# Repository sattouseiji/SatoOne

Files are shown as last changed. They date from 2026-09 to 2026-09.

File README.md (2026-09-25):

# SatoOne

**Um computador pessoal portátil em desenvolvimento.**

SatoOne combina Linux, tela touch e teclado físico em um equipamento compacto, concebido para produtividade móvel, automações e acesso a um ambiente computacional completo.

[**Conheça o SatoOne**](https://sattouseiji.github.io/SatoOne/) · [**Atualização e health check — 25/09**](https://sattouseiji.github.io/SatoOne/reports/satoone-health-2026-09-25.html) · [**Acompanhe o desenvolvimento**](https://github.com/sattouseiji/SatoOne/discussions)

## Estado atual

A versão V0 é um protótipo físico funcional. Já foram integrados e validados:

- Radxa Zero 3W com Debian;
- display touch de 5 polegadas;
- teclado físico integrado;
- conectividade Wi-Fi e periféricos USB;
- funcionamento portátil por bateria;
- gabinete próprio produzido por impressão 3D.

A [página oficial](https://sattouseiji.github.io/SatoOne/) apresenta fotos e uma demonstração em vídeo do protótipo real em funcionamento.

O baseline elétrico atual usa **LiPo Rontek 1S 10 Ah + UPS antigo sem suporte 18650**, preservando switch e distribuição. O responsável confirmou funcionamento estável do conjunto completo, com aproximadamente **4,92 V** na saída do UPS. O IP5310 foi testado e permanece experimental, fora da montagem atual.

O health check de 25/09 encontrou recursos e conectividade disponíveis, mas falha na inicialização do aplicativo e atenção térmica (**73,3–75,6 °C**). As prioridades são corrigir a inicialização, medir o UPS modificado para um Back mais fino e implementar telemetria com INA219. Autonomia mínima de duas horas continua como meta, sem ensaio conclusivo.

A direção inicial de 15–16/09 foi revisada em 25/09/2026 após testes físicos. Consulte o [plano de desenvolvimento V1](docs/development/V1_DEVELOPMENT_PLAN.md), o [sistema de energia](docs/electronics/V1_POWER_SYSTEM.md), o [plano da nova case](docs/cad/V1_ENCLOSURE_PLAN.md) e os [critérios de aceitação](docs/development/V1_ACCEPTANCE_PLAN.md).

## Visão do produto

O objetivo é oferecer um computador realmente pessoal: compacto, configurável e capaz de executar ferramentas Linux sem depender do formato tradicional de notebook.

O projeto está em fase de desenvolvimento e validação. O produto ainda não está disponível para venda, e especificações, formato, preço e cronograma podem mudar.

## Acompanhe e manifeste interesse

As principais etapas serão comunicadas publicamente. Para registrar interesse na versão final, futuras oportunidades de acesso antecipado, health checks, notícias e vídeos, escreva para [sattoumarcelo@gmail.com](mailto:sattoumarcelo@gmail.com) ou participe das [discussões oficiais](https://github.com/sattouseiji/SatoOne/discussions). O programa de atualizações ainda está em preparação.

Preço e formas de pagamento serão anunciados em breve. Manifestar interesse não constitui reserva, compra, investimento, garantia de acesso antecipado ou garantia de lançamento.

## Propriedade intelectual

SatoOne é um projeto de produto proprietário. O conteúdo desta versão é disponibilizado somente para acompanhamento e avaliação. Consulte o arquivo [LICENSE](LICENSE) para os termos aplicáveis.

Versões anteriores que tenham sido expressamente publicadas sob outra licença permanecem sujeitas aos termos válidos no momento de sua publicação.

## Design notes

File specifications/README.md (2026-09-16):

# Specifications

Esta pasta é a fonte de verdade por disciplina. Cada mudança deve declarar estado (`[PHYSICALLY VALIDATED]`, `[CURRENT DESIGN]`, `[PURCHASED]`, `[IN TRANSIT]`, `[PENDING VALIDATION]` ou `[FUTURE/IDEA]`), evidência e data de atualização. Informação substituída permanece marcada como `SUPERSEDED`.

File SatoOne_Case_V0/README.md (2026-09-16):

# SatoOne Case V0 — definitiva

Status: **PHYSICALLY VALIDATED / V0 DEFINITIVA**

Estes são os arquivos de impressão preservados da case usada na V0 funcional do SatoOne.

## Arquivos

- `SatoOne_Case_V0_Front.stl`: frente, originada de `SatoOne_V3_1_FRONT_ORIGINAL_HOLES_M2x5.stl`;
- `SatoOne_Case_V0_Back.stl`: traseira com abertura do UPS, originada de `SatoOne_V3_5_BACK_UPS_Opening_20_40x11_76 (1).stl`;
- `SatoOne_Case_V0_Clamps.stl`: conjunto de presilhas, originado de `SatoOne_V2_6_CLAMPS_ALL.stl`.

Os nomes antigos permanecem registrados aqui para rastreabilidade; o conteúdo geométrico não foi alterado durante a organização para Git.

## Validação

A montagem V0 foi concluída e funciona com Radxa Zero 3W, display Waveshare 5DP-CAPLCD-H, touchscreen USB, BBQ20KBD, hub USB e UPS.

Na revisão funcional mais recente, Radxa e hub trocaram de posição, o hub ficou próximo à parede, a ventilação acompanhou a Radxa e a profundidade nominal do Back foi reduzida de 40 para 34 mm. O pitch de projeto da Radxa é 58 × 23 mm com postes de 10 mm; o pitch atual validado do hub é 52 × 15,25 mm. Essas notas não alteram os STLs preservados.

## Impressão

As configurações exatas de material, orientação, suporte e perfil do slicer usadas na validação física ainda precisam ser registradas. Não inventar parâmetros ausentes.

## Fonte editável

Esta entrega contém as malhas STL definitivas. O arquivo CAD paramétrico/editável correspondente não estava presente nesta pasta na preparação inicial do repositório. Adicioná-lo futuramente sem substituir silenciosamente estes STLs.

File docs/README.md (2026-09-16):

# Documentação de engenharia

Use esta pasta para documentação que explica como construir, operar, integrar e entregar o SatoOne. As regras e requisitos normativos permanecem em `specifications/`.

## Rotas principais

- `product/`: posicionamento comercial e política de comunicação pública.
- `development/V1_DEVELOPMENT_PLAN.md`: plano integrado da V1.
- `development/V1_ACCEPTANCE_PLAN.md`: critérios e gates de validação.
- `electronics/V1_POWER_SYSTEM.md`: energia, proteção e telemetria.
- `cad/V1_ENCLOSURE_PLAN.md`: direção de case e cooling.

As decisões técnicas atuais da V1 foram tomadas em 2026-09-15 e consolidadas na documentação em 2026-09-16.

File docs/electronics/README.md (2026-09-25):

# Eletrônica

A montagem atual usa **LiPo 10 Ah → UPS antigo sem suporte 18650 → switch → distribuição existente**, validada conforme relato físico com ~4,92 V sob carga completa. IP5310 permanece experimental; INA219, autonomia e monitoramento são próximos passos.

Ver [sistema de energia](V1_POWER_SYSTEM.md) e [registro físico de 25/09](../../knowledge/hardware/2026-09-25-power-baseline.md).

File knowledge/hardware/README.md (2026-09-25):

# Hardware

## Baseline atual — 2026-09-25

LiPo 10 Ah recebida e integrada ao UPS antigo sem suporte 18650; saída ~4,92 V estável com o sistema completo, conforme relato do responsável. IP5310 testado e não adotado. Ver [medidas, validação e pendências](2026-09-25-power-baseline.md). Os estados de compra abaixo são o histórico de 15–16/09; INA219 segue sem confirmação de recebimento ou integração.

## Baseline V0

Radxa Zero 3W, display Waveshare 5DP-CAPLCD-H, teclado BlackBerry Q10/BBQ20KBD, hub USB, UPS e duas 18650 estão fisicamente disponíveis. A V0 funciona e foi registrada em fotos e vídeo.

## Marco de 2026-09-15

- health check integral executado;
- 1h04 registrado inicialmente, mas posteriormente marcado como não definitivo; ensaio final V0 pendente;
- SoC observado em 70,6 °C e pico de 77,5 °C;
- caminho HDMI via flat, touch/teclado via hub e distribuição 5 V pós-switch fisicamente validados;
- Li-Po 1S de 10.000 mAh, IP5310 e INA219 comprados em 2026-09-16 e em trânsito;
- case menor, bateria atrás do teclado e cooling condicionado a testes definidos como direção mecânica.

Os itens H018, H019 e H025 estão comprados/em trânsito, mas não fisicamente validados. Consultar o BOM para itens superseded, opcionais e pendentes.

Registrar compatibilidade, medições, testes de integração e substituições. Atualizar o BOM sempre que o status de compra ou peça mudar.

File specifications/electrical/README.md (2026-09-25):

# Electrical

## Baseline atual — 2026-09-25

**[CURRENT WORKING DESIGN] [PHYSICALLY VALIDATED — relato do responsável]**

`LiPo 1S 10 Ah → UPS antigo sem suporte 18650 → switch → distribuição existente`.

Saída relatada ~4,92 V sob carga completa, sem desligamentos ou brownout observado. Preservar a PCB e seus componentes. IP5310 fora da montagem atual, apenas experimental. [Registro físico e limites](../../knowledge/hardware/2026-09-25-power-baseline.md). As seções abaixo preservam o histórico.

## V0 [PHYSICALLY VALIDATED]

```text
2×18650 → LX-2BUPS/equivalente → switch no +5 V → barramento
                                                  ├─ Radxa
                                                  ├─ Hub
                                                  └─ Display
```

- cargas principais usam ramos próprios; Radxa/hub não distribuem a potência total;
- GND é comum e não passa pelo switch;
- a fiação pós-switch está pronta e funcional;
- adaptadores USB-C macho → borne são passivos;
- aproximadamente 4,8 V foram observados com o sistema e YouTube em operação;
- em bateria baixa, células chegaram a ~2,9 V sob carga/~3,14 V em repouso e a saída colapsou para ~2,0 V após desligamento;
- com switch OFF, as cargas desligam, mas o UPS e seu LED permanecem energizados.

O registro anterior de 1h04 fica **SUPERSEDED como autonomia definitiva**. O ensaio com carga completa iniciado em 2026-09-15 às ~18:40 ainda não possui duração final validada.

## Plano V1 de 16/09 [SUPERSEDED em 25/09]

`Li-Po 1S 10 Ah → IP5310 → 5 V → switch existente → distribuição existente`.

Li-Po, IP5310 e INA219 estão [PURCHASED] [IN TRANSIT], com entrega prevista até 2026-09-19. Validar antes da integração:

- medidas, etiqueta, A58/polaridade, tensão, PCM/BMS e capacidade/corrente da bateria;
- pinout, 5 V sem carga/sob carga, corrente, temperatura, proteções e operação simultânea do IP5310;
- limite, queda, dissipação e posição do INA219 antes ou depois do boost;
- coexistência entre Power dedicado da tela e VBUS do USB Touch.

Fusível/PPTC é [OPTIONAL / FUTURE]. A arquitetura anterior com charger/boost separados, fusível 7,5 A obrigatório, XT30, AWG18, MAX17048 e INA226 fica **SUPERSEDED** para a primeira integração.

Nunca ligar Li-Po 1S diretamente a cargas de 5 V, assumir pinout ou usar a saída regulada de 5 V como porcentagem de bateria. Consultar `docs/electronics/V1_POWER_SYSTEM.md` e `skills/satoone-development/references/27_power.md`.

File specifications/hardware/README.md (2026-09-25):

# Hardware

Especifica plataforma, componentes físicos, interfaces e compatibilidade. Consulte `BOM.md` antes de comprar, instalar ou substituir peças.

## Observação operacional — 2026-09-17

[PHYSICALLY VALIDATED — leitura no dispositivo] O sistema auditado usa microSD de 59,5 GiB (classe nominal de 64 GB) para a partição raiz; a eMMC de 29,1 GiB (classe nominal de 32 GB) está presente e não hospeda a raiz atual. Essa observação não altera a capacidade interna especificada da Radxa. Ver `knowledge/benchmarks/2026-09-17-health-check.md` e H031 no BOM. Fabricante, marcação física e compra do cartão não foram verificados.

## Atualização operacional — 2026-09-25

A raiz está na eMMC de 29,1 GiB; nenhum microSD foi enumerado nesta coleta. A observação de 17/09 acima descreve o boot daquela data. Alimentação atual: LiPo 10 Ah + UPS antigo sem suporte 18650; ver [baseline físico](../../knowledge/hardware/2026-09-25-power-baseline.md).

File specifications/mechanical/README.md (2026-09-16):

# Mechanical

## V0 definitiva

A V0 física está funcional e seus três STLs permanecem preservados em `SatoOne_Case_V0/`. O envelope externo anteriormente registrado é aproximadamente 130 × 155 × 44 mm. A profundidade nominal do Back foi reduzida de 40 para 34 mm na iteração funcional; esses valores descrevem referências diferentes e não devem ser combinados sem nova medição. O CAD paramétrico correspondente não está presente; não tratar STL como fonte editável.

Layout mais recente: Radxa e hub trocaram de posição; hub junto à parede, Radxa na região anterior do hub e ventilação acompanhando a Radxa. Mounting pitch de projeto: Radxa 58 × 23 mm; hub fisicamente validado 52 × 15,25 mm. Postes da Radxa: 10 mm de altura.

## V1 comercial — decisão de 2026-09-15

- colocar a bateria pouch atrás do teclado;
- remover o volume do UPS e das duas 18650;
- reduzir significativamente o Back usando a pouch anunciada com ~11,1 mm e o IP5310 compacto, sem fixar dimensão final antes do recebimento;
- manter bateria, eletrônica, display e teclado removíveis;
- não comprimir nem colar permanentemente a Li‑Po;
- preservar acesso a portas e alívio de cabos;
- melhorar caminho térmico e ventilação passiva;
- reservar fan de 30 mm, instalando-o somente se ensaios exigirem.

Criar nova fonte paramétrica para a V1 sem sobrescrever a V0. Produzir coupons para bateria, conectores, standoffs, insertos, ventilação e cabos antes da impressão completa. Consultar `docs/cad/V1_ENCLOSURE_PLAN.md`.

## Fabricação

Projetar dentro do volume da Bambu Lab A1 Mini. PLA serve para protótipos; escolher material de produção somente após térmica, impacto, acabamento e processo de montagem serem validados.

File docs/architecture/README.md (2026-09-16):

# Arquitetura

Árvore de software: GUI → Widgets → Services → Drivers → Database → AI → Network → Storage. Dependências fluem para baixo; widgets não concentram regra de negócio.

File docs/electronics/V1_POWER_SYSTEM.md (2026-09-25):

# Sistema de energia e telemetria — V1

## Revisão vigente — 2026-09-25

**LiPo 10 Ah → UPS antigo sem suporte 18650 → switch → distribuição existente.** Validada fisicamente conforme relato do responsável: ~4,92 V estáveis com o conjunto completo, sem desligamentos ou brownout observado. Preservar PCB, boost, carga e conectores; não cortar a placa.

LiPo recebida: 111,2 × 64,99 × 10,99 mm medidos; CAD 111,2 × 65,0 × 11,0 mm. Proteção integrada observada. IP5310 testado e não adotado; apenas experimental. INA219, autonomia, alertas e shutdown permanecem pendentes. Ver [evidências e próximos passos](../../knowledge/hardware/2026-09-25-power-baseline.md).

## Histórico de 16/09 — plano IP5310 [SUPERSEDED]

O plano e a sequência de testes abaixo são preservados como histórico; não orientam a montagem atual.

**Direção técnica:** 2026-09-15
**Compra registrada:** 2026-09-16
**Estado:** componentes principais [PURCHASED] [IN TRANSIT], entrega prevista até 2026-09-19

## Arquitetura proposta em 16/09 [SUPERSEDED]

```text
Li-Po Rontek/A58 1S 10 Ah
  → módulo IP5310
  → saída 5 V
  → switch mecânico existente no positivo
  → distribuição pós-switch existente
      ├─ Radxa
      ├─ Hub
      └─ Display
```

A fiação após o switch está pronta e fisicamente validada. A próxima alteração deve ocorrer somente antes do switch. GND permanece comum. Radxa e hub não devem ser usados como distribuidores principais de potência.

## Hardware comprado [PENDING VALIDATION]

| Item | Dados de anúncio/compra | Verificar no recebimento |
| --- | --- | --- |
| Li-Po | Rontek/A58, família 1165110, 1S, ~3,7 V, 10.000 mAh/~37 Wh, 1C, 113,5 × 65 × 11,1 mm | medidas, rótulo, tensão, A58/polaridade, PCM/BMS, capacidade/corrente |
| IP5310 | 1S, boost 5 V/~3,1 A, USB-C, carga integrada/power-path, ~26 × 19 × 4,9 mm | pinout, saída sem/sob carga, temperatura, proteções e uso durante carga |
| INA219 | shunt R100, borne, VCC/GND/SDA/SCL | limite de corrente, dissipação, queda, resolução e posição elétrica |

Compra não comprova especificação, compatibilidade ou segurança. Não criar encaixes finais antes de medir as peças reais.

## Telemetria

A posição do INA219 permanece [PENDING DESIGN DECISION]:

- antes do boost: melhor visibilidade da bateria;
- depois do boost: consumo agregado do sistema em 5 V.

A saída regulada de 5 V não serve sozinha como porcentagem da bateria. O software deverá mostrar carga estimada, tensão, corrente, potência e runtime; emitir low-battery warning e executar shutdown limpo antes do colapso.

## Proteção e conexão

- PCM/BMS do pack: [VERIFY EXACT PACK PROTECTION].
- Conector: A58 fêmea com rabicho, preferencialmente 22 AWG, [TO BUY / VERIFY].
- Fusível/PPTC: [OPTIONAL / FUTURE] para a primeira montagem; reavaliar na versão final.
- Não cortar o A58 original se houver conector compatível.
- Nunca ligar a Li-Po diretamente a componentes de 5 V.

## Arquitetura superseded

A recomendação anterior de charger e boost separados, boost 5 A, fusível obrigatório de 7,5 A, XT30, AWG18, MAX17048 e INA226 está **SUPERSEDED para a primeira integração V1**. Esses itens podem voltar como alternativas se os testes do IP5310/INA219 falharem.

## Teste ordenado

1. Fotografar e medir os três módulos.
2. Inspecionar bateria e identificar pinout do IP5310.
3. Testar Li-Po → IP5310 sem carga e confirmar aproximadamente 5 V.
4. Testar Radxa; Radxa + hub; sistema completo.
5. Medir tensão/temperatura com Wi-Fi, YouTube, tela, touch e teclado.
6. Testar carga USB-C durante o uso.
7. Decidir e integrar INA219.
8. Implementar leitura Debian, alertas e shutdown.
9. Medir autonomia.
10. Somente então redesenhar o Back.

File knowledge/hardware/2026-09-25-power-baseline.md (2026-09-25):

# Baseline elétrico — registro de 2026-09-25

**[CURRENT WORKING DESIGN] [PHYSICALLY VALIDATED — relato do responsável]**
Fonte: decisão e medições físicas fornecidas pelo responsável nesta data; não são medições feitas pelo health check SSH. Protótipo, sem qualificação de produção.

## Montagem adotada

`LiPo Rontek 1S 10 Ah → UPS antigo sem suporte 18650 → switch → distribuição existente`.

O banco do UPS foi confirmado como 1S/paralelo, com ~3,6 V na bateria original. Foram removidos apenas suporte e contatos das células cilíndricas; PCB principal, boost, carga, capacitores, indutor, USB-C e saídas foram preservados. Não cortar a PCB nem remover componentes para reduzir tamanho.

## Validação relatada

- **MEDIÇÃO FÍSICA:** saída UPS+/UPS− em aproximadamente **4,92 V** com Radxa, display, touch, hub e teclado funcionando simultaneamente.
- Funcionamento estável, sem desligamentos, queda significativa ou brownout observado.
- Bateria permaneceu fria e UPS em temperatura normal, conforme observação qualitativa; não foram fornecidas temperaturas numéricas.
- LiPo Rontek / 1165110: 1S, 3,7 V e 10.000 mAh nominais; PCB de proteção integrada observada.
- **MEDIÇÃO FÍSICA da LiPo:** **111,2 × 64,99 × 10,99 mm**. Referência arredondada para CAD: **111,2 × 65,0 × 11,0 mm**.

A duração do teste, corrente, capacidade efetiva e limiares da proteção não foram fornecidos. O relato valida a operação observada; autonomia e ensaio sustentado continuam pendentes.

## Alternativa testada

IP5310: carregamento, LEDs/status, boost e cargas USB-C compatíveis funcionaram, mas a integração por fios/pads no SatoOne não teve a mesma confiabilidade do UPS antigo. **[NOT USED IN CURRENT BUILD] [EXPERIMENTAL / FUTURE]**. Não substituir automaticamente o baseline.

## Próximos passos

- [x] LiPo recebida, medida e integrada; proteção observada.
- [x] Banco 1S confirmado, suporte 18650 removido e conjunto completo validado conforme relato.
- [ ] Medir dimensões finais e altura máxima da PCB do UPS.
- [ ] Planejar LiPo e UPS no mesmo plano, Back mais fino, fixação segura/removível, acesso à USB-C de carga e organização dos cabos.
- [ ] Integrar INA219, monitoramento, alerta de bateria baixa e shutdown seguro.
- [ ] Medir autonomia e térmica em cenário documentado.

Esta revisão substitui a direção IP5310 de 16/09. A distribuição pós-switch permanece preservada.

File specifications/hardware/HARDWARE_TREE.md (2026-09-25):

# Hardware Tree

```text
SatoOne V0 [PHYSICALLY VALIDATED]
├── Compute             Radxa Zero 3W, 4 GB, 32 GB eMMC
├── Display             Waveshare 5DP-CAPLCD-H, HDMI + touch USB
├── Keyboard            BlackBerry Q10 / BBQ20KBD via hub
├── Video               micro-HDMI → adaptador/flat → HDMI flat Waveshare
├── Energy              2×18650 → LX-2BUPS/equiv. → switch positivo
├── Distribution        barramento 5 V/GND → ramos Radxa, hub e display
├── USB                 Radxa → hub → touch + teclado
└── Enclosure           case V0 impressa e funcional

SatoOne atual — 2026-09-25 [CURRENT WORKING DESIGN]
├── Battery             LiPo Rontek 1S 10 Ah [RECEIVED] [PHYSICALLY VALIDATED]
├── Energy              UPS antigo sem suporte 18650, ~4,92 V sob carga
├── Switch              switch mecânico existente no positivo
├── Distribution        fiação pós-switch existente preservada
├── Telemetry           INA219 R100 [PURCHASED] [IN TRANSIT]
├── Connector           A58 fêmea com rabicho 22 AWG [TO BUY / VERIFY]
├── Protection          PCB de proteção da LiPo observada; limiares não ensaiados
├── Cooling             passivo primeiro; fan 30 mm condicional
└── Enclosure           LiPo e UPS no mesmo plano; medir PCB/altura do UPS
```

A arquitetura anterior de charger/boost separados, fusível 7,5 A, XT30, AWG18, MAX17048 e INA226 fica **SUPERSEDED** para a primeira montagem V1. Compra não implica validação física; consultar `skills/satoone-development/references/27_power.md`.

IP5310: [NOT USED IN CURRENT BUILD] [EXPERIMENTAL / FUTURE]. INA219: integração futura; recebimento não reconfirmado. Fonte: [baseline de 25/09](../../knowledge/hardware/2026-09-25-power-baseline.md).

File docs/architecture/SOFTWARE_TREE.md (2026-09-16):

# Software Tree

```text
GUI
└── Widgets
    └── Services
        └── Drivers
            └── Database
                └── AI
                    └── Network
                        └── Storage
```

Widgets exibem estado e encaminham intenção; serviços contêm casos de uso; drivers isolam hardware; repositórios isolam persistência. A árvore descreve dependências lógicas, não autoriza chamadas bloqueantes na UI.

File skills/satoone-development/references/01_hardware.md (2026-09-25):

# Hardware — estado em 2026-09-16

**Atualização — 2026-09-25:** a montagem vigente é LiPo 10 Ah → UPS antigo sem suporte 18650 → switch → distribuição existente, validada fisicamente conforme relato do responsável. O IP5310 foi testado e não adotado; permanece experimental. Ver [baseline atual](../../../knowledge/hardware/2026-09-25-power-baseline.md). As referências de 16/09 abaixo são históricas; o plano com IP5310 está **SUPERSEDED**.

## V0 funcional [PHYSICALLY VALIDATED]

| Item | Estado atual |
| --- | --- |
| Radxa | Zero 3W, 4 GB RAM, 32 GB eMMC, GPIO instalado, Debian, Wi-Fi e YouTube funcionais |
| Display | Waveshare 5DP-CAPLCD/5DP-CAPLCD-H, 5", 1024×600, 122,76 × 77,28 mm, espessura máxima aproximada 17,38 mm |
| Teclado | BlackBerry Q10/BBQ20KBD; PCB 77,89 × 53,39 mm; área visível 68,32 × 42,43 mm; espessura aproximada 7,11 mm |
| Hub | USB 2.0 1→4; PCB aproximada 57 × 30 × 13,90 mm; mounting pitch atual 52,00 × 15,25 mm |
| Energia | LX-2BUPS/equivalente, 2×18650, barramento pós-switch com ramos separados para Radxa, hub e display |

O mounting pitch anterior do hub, 43,35 × 10,61 mm, fica **SUPERSEDED** pelo padrão atual fisicamente validado de 52,00 × 15,25 mm. Os quatro postes devem formar retângulo simétrico; standoff OD 5,0 mm, altura 4,0 mm e piloto aproximado 2,20 mm.

## Vídeo e USB [PHYSICALLY VALIDATED]

Vídeo: `Radxa micro-HDMI → adaptador HDMI/flat → cabo flat HDMI → entrada HDMI flat Waveshare`. O FPC da Radxa não é HDMI/display e não integra a tela atual. Meta de vídeo: 1024×600 a 60 Hz; áudio pode trafegar por HDMI.

USB: `Radxa USB → hub → touch Waveshare + teclado`. Touch e teclado funcionam. O USB-C Touch da tela também transportou 5 V/VBUS e conseguiu alimentá-la. A coexistência do Power dedicado com o VBUS do Touch ainda exige validação contra backfeed; não cortar VBUS nem assumir isolamento antes dessa verificação.

## Plano V1 de 16/09 [SUPERSEDED]

Li-Po 1S 10.000 mAh → IP5310 → switch geral → distribuição 5 V já existente. Li-Po, IP5310 e INA219 estão [PURCHASED] [IN TRANSIT], com entrega prevista até 2026-09-19. Não desenhar fixação final nem assumir pinout, medidas, PCM/BMS ou desempenho antes do recebimento e inspeção.

Manter USB-C, micro-HDMI, microSD, áudio, UART, USB OTG, GPIO, I²C, SPI e PWM acessíveis conforme a integração. Consultar `27_power.md` antes de qualquer alteração elétrica.

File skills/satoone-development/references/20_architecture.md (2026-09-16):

# Arquitetura

Consultar `docs/architecture/`. A dependência lógica é GUI → Widgets → Services → Drivers → Database → AI → Network → Storage. Preserve MVC e isole hardware em adaptadores.

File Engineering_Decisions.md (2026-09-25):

# Engineering Decisions — SatoOne

**Versão:** 1.3
**Status:** Registro canônico de decisões  
**Última atualização:** 2026-09-25

## Propósito e regra

Registrar por que cada decisão relevante foi tomada, as alternativas avaliadas, sua evidência, consequências e gatilhos de revisão. Uma decisão não é uma medição: hipóteses e itens planejados devem permanecer explícitos.

## Índice

| ID | Decisão | Estado | Gatilho de revisão |
| --- | --- | --- | --- |
| ADR-001 | MVC com Python/PySide6 | Aceita | Limite de desempenho/integração comprovado |
| ADR-002 | Radxa Zero 3W | Aceita | Evidência de insuficiência de hardware |
| ADR-003 | Debian Bullseye + XFCE | Aceita | Necessidade de driver/segurança/manutenção |
| ADR-004 | Virtualenv do projeto | Aceita | Empacotamento substitui fluxo atual |
| ADR-005 | Launcher para autostart | Aceita | Método de deploy mais robusto validado |
| ADR-006 | Waveshare 5" atual / 4" futuro | Em validação | Testes do display 4" |
| ADR-007 | Teclado BlackBerry Q10 | Aceita | Integração física/eletrônica inviável |
| ADR-008 | Bambu Lab A1 Mini; PLA V1 | Aceita | Requisitos mecânicos/térmicos exigirem mudança |
| ADR-009 | Gabinete modular e reparável | Aceita | Nenhum; princípio de produto |
| ADR-010 | Knowledge base e skills | Aceita | Processo comprovadamente inadequado |
| ADR-011 | Produto proprietário com desenvolvimento público | Aceita | Estratégia comercial formal mudar |
| ADR-012 | Li‑Po 1S 10.000 mAh e IP5310 | SUPERSEDED por ADR-015 | Histórico preservado |
| ADR-015 | LiPo 10 Ah + UPS antigo sem holder | Validada fisicamente — relato | Nova evidência elétrica ou mecânica |
| ADR-013 | Telemetria de bateria integrada ao Debian | Em validação | Driver/kernel ou precisão insuficientes |
| ADR-014 | Case V1 menor com cooling orientado por testes | Em validação | CAD, segurança ou térmica inviabilizar |

## Decisões detalhadas

### ADR-001 — MVC com Python e PySide6

- **Contexto:** GUI Linux embarcada precisa evoluir sem misturar apresentação e regra de negócio.
- **Alternativas:** UI monolítica; frameworks proibidos em `Constraints.md` (Tkinter, PyQt, Electron e JavaScript para GUI).
- **Decisão:** MVC, Python e PySide6, com serviços e drivers isolados.
- **Motivo:** separação de responsabilidades, testabilidade, suporte Linux e interface nativa.
- **Consequência:** não bloquear a thread UI; widgets não carregam regra de negócio.

### ADR-002 — Radxa Zero 3W como plataforma-alvo

- **Contexto:** computador portátil de IA requer placa compacta e Linux.
- **Alternativas:** não registradas no histórico disponível.
- **Decisão:** Radxa Zero 3W com 4 GB LPDDR4 e 32 GB eMMC.
- **Motivo:** suporte Linux, consumo, Wi-Fi/Bluetooth e formato compacto.
- **Risco:** IA, temperatura e armazenamento são recursos limitados; medir no dispositivo.

### ADR-003 — Debian Bullseye com XFCE

- **Contexto:** definir ambiente operacional repetível.
- **Decisão:** Debian Bullseye e XFCE.
- **Motivo:** estabilidade, baixo peso e compatibilidade Qt.
- **Consequência:** dependências e deployment devem ser documentados para esta base.

### ADR-004 — Virtualenv dentro do projeto

- **Contexto:** dependências Python precisam ser isoladas e encontráveis.
- **Decisão:** `~/Projetos/SatoOne/.venv`.
- **Motivo:** isolamento, repetibilidade e backup.
- **Evidência:** corrigiu o diagnóstico registrado em `ERROR-0004`.

### ADR-005 — Autostart por launcher

- **Contexto:** `.desktop` não ativava o virtualenv ao chamar Python diretamente.
- **Decisão:** usar `.desktop` → `start_satoone.sh` → ativação de `.venv` → aplicação.
- **Motivo:** garantir ambiente correto no login gráfico.
- **Evidência:** `SUCCESS-0006`; ver `ERROR-0005`.

### ADR-006 — Estratégia de displays

- **Contexto:** Waveshare HDMI 5", 1024×600, compatível; proporção com Q10 é insatisfatória.
- **Decisão:** manter display atual no protótipo e avaliar HDMI IPS 4", 720×720, capacitivo.
- **Motivo:** melhor proporção e aparência comercial.
- **Estado:** em validação; não comprar/considerar compatível sem testes documentados.

### ADR-007 — Teclado BlackBerry Q10

- **Contexto:** handheld precisa de digitação física e aparência profissional.
- **Decisão:** usar Q10 como referência de design.
- **Motivo:** experiência de digitação, compactação e linguagem visual.
- **Risco:** integração e disponibilidade ainda exigem validação.

### ADR-008 — Prototipagem com Bambu Lab A1 Mini

- **Contexto:** construir e iterar gabinete localmente.
- **Decisão:** Bambu Lab A1 Mini; PLA na V1 e PETG como evolução futura.
- **Motivo:** precisão, confiabilidade e software.
- **Consequência:** CAD precisa respeitar envelope, orientação, inserts e manutenção.

### ADR-009 — Gabinete modular e reparável

- **Decisão:** gabinete do zero, com manutenção, compartimento de bateria, cantos arredondados, parafusos ocultos e rota interna de cabos.
- **Motivo:** objetivo comercial e vida longa do produto.
- **Alternativas descartadas:** gabinete sem manutenção e fixação improvisada são incompatíveis com a visão.

### ADR-010 — Documentação e skills como memória permanente

- **Decisão:** especificações, knowledge base, histórico e skills são partes do produto.
- **Motivo:** evitar perda de conhecimento e repetição de erros; permitir contribuição consistente de pessoas e agentes.
- **Consequência:** toda mudança relevante atualiza a documentação relacionada.

### ADR-011 — Produto proprietário com desenvolvimento público

- **Data:** 2026-09-15; consolidada publicamente em 2026-09-16.
- **Decisão:** posicionar o SatoOne como produto proprietário e usar o site/repositório público para acompanhamento, interesse de compra, parcerias e apoio.
- **Motivo:** preparar uma proposta comercial coerente sem apresentar o projeto como convite aberto à fabricação ou desenvolvimento.
- **Consequência:** comunicação pública sanitizada; detalhes internos e futuros ativos estratégicos devem migrar para engenharia privada.
- **Limite:** versões já publicadas sob MIT continuam sujeitas à licença aplicável àquelas versões.

### ADR-012 — Nova cadeia de energia da V1

- **Data:** 2026-09-15.
- **Atualização:** 2026-09-16.
- **Decisão de 16/09 [SUPERSEDED por ADR-015 em 25/09]:** Li-Po 1S 10.000 mAh → IP5310 → switch mecânico existente → distribuição 5 V existente.
- **Motivo:** reduzir o volume do LX-2BUPS/18650 e preservar o trecho pós-switch já funcional.
- **Compra:** Li-Po e IP5310 [PURCHASED] [IN TRANSIT], entrega prevista até 2026-09-19.
- **SUPERSEDED:** charger/boost separados, fusível obrigatório de 7,5 A, XT30, AWG18 e comutação por `EN` não integram a primeira montagem atual.
- **Pendente:** confirmar PCM/BMS, A58/polaridade, pinout, 5 V/3,1 A e power-path no hardware recebido.
- **Meta:** pelo menos duas horas no ensaio definido.

### ADR-013 — Telemetria no Debian

- **Data:** 2026-09-15.
- **Atualização:** 2026-09-16.
- **Decisão atual:** validar o INA219 R100 comprado e decidir sua instalação antes ou depois do boost.
- **Motivo:** o UPS atual não fornece nível útil ao Linux.
- **SUPERSEDED:** MAX17048 + INA226 deixam de ser a primeira integração, mas permanecem alternativas futuras se o INA219 for inadequado.
- **Consequência:** criar driver/serviço isolado da UI, não inferir carga pela saída fixa de 5 V e implementar alerta/shutdown seguro após validar a medição.

### ADR-014 — Direção mecânica e térmica da V1

- **Data:** 2026-09-15.
- **Decisão:** colocar a bateria pouch atrás do teclado, reduzir espessura e priorizar dissipação passiva; reservar fan de 30 mm apenas se testes exigirem.
- **Meta preliminar:** região da bateria entre 25 e 28 mm; SoC sustentado ≤75 °C sem throttling.
- **Limite:** metas dependem de CAD, folgas de segurança e validação física.

### ADR-015 — Manter UPS antigo com LiPo 10 Ah

- **Registro:** 2026-09-25; substitui o plano com IP5310 da ADR-012.
- **Decisão:** LiPo 1S → UPS antigo sem suporte 18650 → switch → distribuição existente.
- **Motivo/evidência:** responsável confirmou ~4,92 V e funcionamento estável com o conjunto completo; IP5310 por fios/pads não apresentou a mesma confiabilidade.
- **Limites:** autonomia e telemetria pendentes; proteção integrada observada, sem ensaio dos seus limiares.
- **Próximo passo:** medir PCB/altura do UPS, posicionar LiPo e UPS no mesmo plano e reduzir o Back. Não cortar PCB ou remover eletrônica funcional.
- **Fonte:** [registro físico e limites](knowledge/hardware/2026-09-25-power-baseline.md).

## Template

### ADR-### — Título

- **Data:**
- **Status:** Proposta / Aceita / Em validação / Substituída
- **Contexto:**
- **Alternativas consideradas:**
- **Decisão:**
- **Motivo e evidência:**
- **Consequências e riscos:**
- **Gatilho de revisão:**
- **Links relacionados:**

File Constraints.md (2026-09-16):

# Restrições não negociáveis

Estas regras orientam pessoas e agentes. Uma exceção exige decisão documentada em `knowledge/decisions.md` e atualização desta justificativa.

- Nunca usar Tkinter, PyQt, Electron ou JavaScript para a GUI principal.
- Usar Python e PySide6 para a GUI, mantendo MVC e lógica de negócio fora de widgets.
- Nunca usar SQLite sem Repository Pattern.
- Nunca usar widgets padrão sem tratamento visual; a interface deve seguir o sistema visual do SatoOne.
- Nunca introduzir cores aleatórias; usar tokens de design definidos em `specifications/ui/`.
- Não criar arquivos com mais de 500 linhas, classes com mais de 400 linhas ou métodos com mais de 40 linhas sem justificativa documentada.
- Nunca usar variáveis globais mutáveis como estado de aplicação.
- Nunca bloquear a thread da UI com I/O, IA, rede ou leitura de hardware.
- Nunca assumir que periféricos ou rede estão presentes; expor falhas como estados visíveis.
- Nunca apagar ou reescrever histórico de engenharia: corrigir com uma nova entrada datada.
- Nunca apresentar meta, estimativa, anúncio de fornecedor ou componente candidato como especificação validada.
- Nunca conectar uma Li‑Po 1S diretamente ao barramento de 5 V; usar proteção, power-path e conversão regulada adequados.
- Nunca comprimir, perfurar, colar permanentemente ou montar a bateria sem folga, isolamento e alívio mecânico.
- Nunca publicar no site informações de rede interna, credenciais, postura detalhada de segurança ou evidência operacional sensível.
- Nunca tratar o repositório público como autorização de cópia, fabricação ou comercialização; respeitar a licença proprietária atual e o histórico de licenças anteriores.
- Sempre consultar hardware, wiring e power antes de alterar alimentação; nunca assumir pinout, tensão, polaridade ou isolamento.
- O sistema atual opera em 5 V; USB de dados e USB de potência devem ser tratados separadamente.
- Nunca usar a Radxa ou o hub como distribuidor principal de potência; cargas principais recebem ramos próprios do barramento pós-switch.
- Preservar a fiação pós-switch fisicamente validada; a próxima troca elétrica ocorre antes do switch, salvo decisão posterior documentada.
- Medida física com paquímetro prevalece sobre anúncio, catálogo e estimativa.
- Nunca desenhar encaixe final para componente em trânsito antes de medi-lo fisicamente.

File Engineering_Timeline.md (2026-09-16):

# Engineering Timeline — SatoOne

**Versão:** 1.3
**Status:** Linha do tempo canônica  
**Última atualização:** 2026-09-16

## Regra de data

O material histórico importado não contém datas originais. Por integridade, estes eventos são sequenciados logicamente, não datados artificialmente. À medida que logs, commits ou fotos forem recuperados, substituir “data histórica não registrada” pela data verificável e adicionar a fonte.

## Linha do tempo

| Ordem | Data | Evento | Resultado / referência |
| --- | --- | --- | --- |
| 01 | Histórica não registrada | Filosofia de produto definida | Qualidade comercial, modularidade, reparabilidade e Linux embarcado (`SUCCESS-0016`) |
| 02 | Histórica não registrada | Plataforma e SO selecionados | Radxa Zero 3W; Debian Bullseye/XFCE (`SUCCESS-0002`, `0003`) |
| 03 | Histórica não registrada | Arquitetura definida | MVC, Python, PySide6 e modularidade (`SUCCESS-0001`) |
| 04 | Histórica não registrada | Virtualenv padronizado | `.venv` do projeto (`SUCCESS-0004`, `ERROR-0004`) |
| 05 | Histórica não registrada | Falha de plugin Qt investigada | `ldd`; instalação de `libxcb-cursor0` (`SUCCESS-0005`, `ERROR-0003`) |
| 06 | Histórica não registrada | Autostart implementado | `.desktop` + `start_satoone.sh` (`SUCCESS-0006`, `ERROR-0005`) |
| 07 | Histórica não registrada | Primeira splash criada | Logo, status, progresso e mensagens (`SUCCESS-0007`) |
| 08 | Histórica não registrada | Timer da splash validado | 100 ticks; lacuna era visual, não temporal (`SUCCESS-0008`, `ERROR-0006`) |
| 09 | Histórica não registrada | Display Waveshare validado | HDMI e touch USB HID no Linux (`SUCCESS-0009`) |
| 10 | Histórica não registrada | Direção de display futuro aprovada | Avaliar HDMI IPS 4", 720×720 (`SUCCESS-0010`, `ERROR-0009`) |
| 11 | Histórica não registrada | Teclado e estratégia mecânica definidos | Q10; gabinete modular/reparável (`SUCCESS-0011`, `0013`) |
| 12 | Histórica não registrada | Impressora 3D selecionada | Bambu Lab A1 Mini (`SUCCESS-0012`) |
| 13 | Histórica não registrada | SSH e systemd compreendidos | Socket activation e journal com privilégios (`ERROR-0001`, `0002`) |
| 14 | Histórica não registrada | Execução modular e debug de serviços ajustados | Import path e restart do systemd (`ERROR-0007`, `0008`) |
| 15 | 2026-08-04 | Estratégia documental e skills materializadas | Engineering Bible, specifications, knowledge e skills (`SUCCESS-0014`, `0015`) |
| 16 | 2026-08-04 | Históricos de erros e acertos importados | 10 erros e 16 sucessos organizados |
| 17 | 2026-08-04 | Registros canônicos elaborados | Este conjunto de quatro arquivos criado |
| 18 | 2026-08-04 | Impressora e filamentos comprados | Bambu Lab A1 Mini; filamentos branco, preto e cinza; entrega prevista para 2026-08-05 |
| 19 | 2026-08-04 | BMCU 370C AMS Lite comprado para testes de cor | Para Bambu Lab A1/A1 Mini; sensor Hall e bufferização bidirecional informados pelo anúncio; entrega pendente |
| 20 | 2026-09-15 | Case V0 definitiva e protótipo operacional registrados | STLs preservados; fotos e vídeo reais; Radxa, display, touch e teclado em funcionamento |
| 21 | 2026-09-15 | Health check integral executado | Recursos com folga; SoC 70,6 °C e pico de 77,5 °C; relatório consolidado |
| 22 | 2026-09-15 | Ensaio V0 com carga completa iniciado | Início por volta de 18:40; duração final permanece pendente; 1h04 anterior não é valor definitivo |
| 23 | 2026-09-15 | Direção de energia V1 definida | Substituir 2×18650/LX-2BUPS por Li-Po 1S e módulo compacto antes do switch |
| 24 | 2026-09-15 | Direção mecânica/térmica V1 definida | Bateria atrás do teclado, case mais fina, cooling passivo e fan opcional |
| 25 | 2026-09-16 | Estratégia comercial consolidada e publicada | Site corporativo, licença proprietária atual, Discussions, health check público, fotos e vídeo |
| 26 | 2026-09-16 | Hardware de energia V1 comprado | Li-Po 10 Ah, IP5310 e INA219 em trânsito; entrega prevista até 2026-09-19 |
| 27 | 2026-09-16 | Arquitetura atual de distribuição consolidada | IP5310 antes do switch; fiação pós-switch preservada; fusível/PPTC opcional |

## Próximos marcos planejados

1. Receber, fotografar e medir Li-Po, IP5310 e INA219 até 2026-09-19.
2. Confirmar proteção/polaridade da bateria e pinout/power-path do IP5310.
3. Validar 5 V e escalar carga de Radxa para sistema completo.
4. Decidir a posição do INA219 e integrar telemetria I²C ao Debian/dashboard.
5. Implementar alerta/shutdown seguro e medir autonomia.
6. Criar a fonte CAD da case V1 somente após as medições reais.

## Template de evento

| Ordem | Data (`YYYY-MM-DD`) | Evento | Evidência / links | Resultado | Próximo passo |
| --- | --- | --- | --- | --- | --- |

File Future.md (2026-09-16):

# Recursos futuros

| Recurso | Estado | Dependências / observações |
| --- | --- | --- |
| OTA | Planejado | Assinatura, rollback e segurança |
| Speech Recognition | Planejado | Avaliar desempenho offline |
| Voice Assistant | Planejado | Depende de reconhecimento de fala |
| Fingerprint | Planejado | Hardware e driver a selecionar |
| Camera | Planejado | Privacidade e driver a validar |
| GPS | Planejado | Módulo e antena a selecionar |
| LoRa | Planejado | Regulamentação e módulo a validar |
| Dock | Planejado | Definir conectividade e energia |
| LTE | Planejado | Módulo, antena e certificação |
| NFC | Planejado | Módulo e casos de uso |
| OLED Status | Planejado | Barramento e consumo a validar |
| Fan | Condicional | Somente se ensaio térmico sustentado exigir |
| Battery dashboard | Em preparação | INA219 comprado/em trânsito; posição elétrica e precisão pendentes |
| Low-battery shutdown | Planejado para V1 | Depende de telemetria confiável e limiar validado |
| Thermal Camera | Planejado | Módulo, custo e caso de uso |
| Série piloto | Planejado | V1 validada, BOM, fornecedores, custo e montagem repetível |
| Lista de interesse | Em estruturação | GitHub Discussions hoje; canal comercial dedicado no futuro |

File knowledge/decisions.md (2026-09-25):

# Decisões de engenharia

## ADR-001 — Plataforma principal

- **Data:** 2026-08-04
- **Decisão:** Radxa Zero 3W com 4 GB RAM e 32 GB eMMC; Debian Bullseye XFCE; Python/PySide6.
- **Motivo:** plataforma Linux embarcada, compatível com a direção offline-first e UI nativa.
- **Alternativas consideradas:** a registrar quando comparadas com evidência.
- **Melhoria futura:** validar imagem, drivers, desempenho térmico e orçamento de RAM no dispositivo.

## ADR-002 — Displays e fabricação

- **Decisão:** Waveshare HDMI 5" atual; avaliar migração a IPS HDMI 4" 720×720. Bambu Lab A1 Mini para protótipos, PLA na V1 e PETG futuro.
- **Motivo:** compatibilidade HDMI/USB HID e uma rota de prototipagem acessível.
- **Melhoria futura:** registrar medições de toque, brilho, temperatura e encaixe mecânico.

## ADR-003 — Inicialização da aplicação

- **Data:** 2026-08-04
- **Decisão:** iniciar o app instalado por um script que ativa o virtualenv; usar execução modular Python em desenvolvimento.
- **Motivo:** uma entrada `.desktop` que executava Python diretamente não ativava `.venv`; executar `python app/splash.py` também removia a raiz do projeto do contexto de importação.
- **Alternativas consideradas:** chamar Python diretamente pela entrada desktop ou executar arquivo interno diretamente; ambas produziram falhas registradas em `ERROR-0005` e `ERROR-0007`.
- **Evidência:** histórico de erros v1.0 importado.
- **Melhoria futura:** documentar os caminhos de instalação reais e fornecer um launcher testado.

## ADR-004 — Enclosure V0 paramétrica e prototipagem iterativa

- **Data:** 2026-08-15
- **Status:** Aceita para protótipo
- **Decisão:** usar `SatoOne_Case_V0/SatoOne_Case_V0.scad` como fonte única de dimensões e iterar V0→V4, começando por coupons de encaixe.
- **Motivo/evidência:** Bambu Lab A1 Mini recebida; envelopes de display, teclado, Radxa, UPS e hub medidos com paquímetro.
- **Limites:** teclado precisa revalidar furos; display precisa desenho oficial da variante H; UPS domina a espessura.

## ADR-005 — Produto proprietário e acompanhamento público

- **Data da decisão:** 2026-09-15.
- **Publicação consolidada:** 2026-09-16.
- **Decisão:** desenvolver o SatoOne como produto vendável proprietário; usar site, health check e Discussions para mostrar evolução e medir interesse.
- **Motivo:** construir valor comercial e preservar a engenharia futura.
- **Limite:** versões antigas publicadas sob MIT mantêm seus termos originais.

## ADR-006 — Energia e telemetria da V1

- **Data:** 2026-09-15.
- **Atualização:** 2026-09-16.
- **Decisão de 16/09 [SUPERSEDED por ADR-009 em 25/09]:** Li-Po 1S 10.000 mAh + IP5310 antes do switch atual; preservar a distribuição pós-switch; validar INA219 antes/depois do boost.
- **Compra:** Li-Po, IP5310 e INA219 [PURCHASED] [IN TRANSIT], entrega prevista até 2026-09-19.
- **SUPERSEDED:** cadeia genérica charger/boost separados, fusível 7,5 A obrigatório, XT30, AWG18, MAX17048 e INA226 não integram a primeira montagem atual.
- **Motivo:** volume do UPS/18650, colapso de tensão em bateria baixa e ausência de telemetria no Debian.
- **Estado:** integração pendente; fusível/PPTC opcional nesta etapa.

## ADR-007 — Case e cooling da V1 comercial

- **Data:** 2026-09-15.
- **Decisão:** bateria atrás do teclado, redução da espessura, dissipação passiva e fan somente se necessário.
- **Metas:** reduzir o Back após medir o hardware recebido; SoC sustentado ≤75 °C sem throttling; autonomia ≥2 h.
- **Estado:** metas ainda não validadas fisicamente.

## ADR-008 — Preservar distribuição pós-switch

- **Data:** 2026-09-16.
- **Decisão:** manter switch, GND comum e ramos de +5 V para Radxa, hub e tela; trocar somente bateria/UPS antes do switch.
- **Evidência:** fiação funciona a aproximadamente 4,8 V com sistema completo e YouTube.
- **Limite:** validar Power dedicado + VBUS Touch contra backfeed.

## ADR-009 — Baseline elétrico revisado — 2026-09-25

A decisão com IP5310 da ADR-006 está **SUPERSEDED**. Manter LiPo 10 Ah + UPS antigo sem suporte 18650, switch e distribuição existentes. O responsável relatou ~4,92 V estáveis com o sistema completo; a integração por fios/pads do IP5310 não foi igualmente confiável. IP5310 segue experimental. Medir PCB/altura do UPS para CAD; autonomia e INA219 seguem pendentes. Ver [evidências](hardware/2026-09-25-power-baseline.md) e ADR-015 no registro canônico.

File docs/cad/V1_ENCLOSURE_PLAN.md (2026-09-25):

# Direção mecânica — Case V1 comercial

**Direção definida:** 2026-09-15
**Estado:** meta de projeto, ainda sem CAD V1 validado

## Baseline

A V0 definitiva possui envelope externo anteriormente registrado de aproximadamente 130 × 155 × 44 mm. A profundidade nominal do Back foi reduzida de 40 para 34 mm; são referências distintas, pendentes de nova medição correlacionada. Ela permanece preservada como prova física funcional e não deve ser sobrescrita.

## Objetivos

- aproveitar o UPS antigo com suporte 18650 já removido, preservando toda a PCB e sua eletrônica;
- posicionar LiPo e UPS preferencialmente no mesmo plano, evitando empilhamento;
- usar a LiPo medida (CAD: 111,2 × 65,0 × 11,0 mm) e medir dimensões/altura máxima do UPS modificado antes de definir a espessura final;
- manter bateria, eletrônica e cabos removíveis e sem compressão;
- preservar acesso a USB-C, HDMI, microSD, áudio, UART e GPIO relevantes;
- melhorar entradas, saídas e caminho de ar;
- reservar espaço e alimentação para ventoinha de 30 mm sem torná-la obrigatória.

## Estratégia térmica

1. Melhorar contato da Radxa com dissipador/espalhador de cobre.
2. Evitar bolsões de ar quente e obstrução das ranhuras.
3. Executar carga sustentada por 20–30 minutos.
4. Buscar temperatura sustentada de SoC igual ou inferior a 75 °C, sem throttling.
5. Instalar cooling ativo somente se a solução passiva não atingir a meta.

## Processo CAD

Criar uma nova fonte paramétrica para a V1; nunca editar os STLs V0 como se fossem fonte. Antes da impressão completa, produzir coupons para bateria, conectores, standoffs, ventilação, insertos e passagem de cabos.

Atualização de 25/09: LiPo recebida e medida; IP5310 fora da montagem. Medir a PCB real do UPS sem holder e seus componentes antes do encaixe final. Prever fixação segura e removível da LiPo, folgas, USB-C de carga acessível e organização dos cabos. Preservar no novo layout o conhecimento da V0: hub próximo à parede, Radxa no lado antes ocupado pelo hub, ventilação alinhada à Radxa, pitch Radxa 58 × 23 mm/postes 10 mm e hub 52 × 15,25 mm.

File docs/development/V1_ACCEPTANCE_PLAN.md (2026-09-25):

# Plano de aceitação — V1

## Critérios mínimos

| Área | Critério |
| --- | --- |
| Autonomia | ≥2 horas no cenário de teste documentado |
| Energia | 5,0 V estáveis, sem reset em pico de carga |
| Bateria | proteção do pack, polaridade, conector e descarga validados; proteção adicional decidida |
| Telemetria | carga, tensão, corrente e potência visíveis no Debian |
| Térmica | meta ≤75 °C sustentados e ausência de throttling |
| Mecânica | sem compressão da Li‑Po; montagem removível e sem interferências |
| UX | alertas de carga e bateria baixa funcionais |

## Ensaio de autonomia

Registrar versão do hardware/software, brilho, Wi‑Fi, carga de CPU, periféricos, horário inicial/final, tensão, corrente, potência e temperaturas. Não comparar resultados de cenários diferentes sem identificá-los.

## Gates

1. **Bancada:** validar módulos sem Radxa.
2. **Integração aberta:** alimentar Radxa e periféricos fora da case.
3. **Integração fechada:** repetir com a case montada.
4. **Sustentado:** executar por pelo menos duas horas.
5. **Decisão térmica:** adicionar fan somente se os dados exigirem.

## Gate de chegada — 2026-09-19 [histórico; IP5310 SUPERSEDED]

Antes dos gates acima: fotografar/medir Li-Po, IP5310 e INA219; confirmar A58/PCM/polaridade; identificar pinout; testar ~5 V sem carga. Preservar a V0 até a nova cadeia passar pelos testes abertos.

## Situação em 2026-09-25

- **Concluído conforme relato físico:** LiPo recebida/medida, proteção integrada observada, banco 1S confirmado, holder removido, LiPo + UPS antigo e conjunto completo funcionando a ~4,92 V.
- **Pendente:** ensaio de autonomia, limites das proteções, carga durante uso, telemetria, novo Back e térmica sustentada. A meta de energia acima não significa que tenham sido medidos exatamente 5,0 V.
- **Aplicativo:** corrigir falha de inicialização antes da aceitação funcional.
- IP5310 não é requisito da montagem atual. Ver [baseline](../../knowledge/hardware/2026-09-25-power-baseline.md).

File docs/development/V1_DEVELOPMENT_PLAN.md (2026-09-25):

# Plano de desenvolvimento — SatoOne V1

**Direção definida:** 2026-09-15
**Publicação consolidada:** 2026-09-16
**Atualização:** 2026-09-25
**Estado:** LiPo 10 Ah + UPS antigo sem holder validados conforme relato físico; software, autonomia, telemetria e novo Back pendentes

## Baseline V0

A V0 executa Debian na Radxa Zero 3W com display touch de 5", teclado físico e alimentação portátil. Fotos e vídeo comprovam a integração. O registro anterior de 1h04 foi marcado como não definitivo; o ensaio iniciado com carga completa em 2026-09-15 ainda está [PENDING VALIDATION]. O health check observou SoC em **70,6 °C**, com pico de **77,5 °C**.

## Objetivos da V1

1. Atingir no mínimo duas horas de autonomia em cenário de teste definido.
2. Manter a LiPo 1S 10 Ah integrada ao UPS antigo sem suporte 18650; IP5310 experimental.
3. Expor percentual, tensão, corrente, potência e autonomia estimada ao Debian.
4. Reduzir o Back com LiPo e UPS preferencialmente no mesmo plano.
5. Melhorar a dissipação passiva e usar ventoinha somente se medições justificarem.
6. Preparar montagem repetível, manutenção e uma futura pequena série piloto.

## Frentes de trabalho

| Frente | Entrega | Estado |
| --- | --- | --- |
| Energia | LiPo 10 Ah + UPS antigo sem holder | ~4,92 V estáveis sob carga completa, relato físico |
| Telemetria | INA219 antes/depois do boost via I²C | Integração futura; recebimento não reconfirmado |
| Mecânica | nova case mais fina e componentes removíveis | Planejada |
| Térmica | caminho passivo e reserva para fan de 30 mm | Planejada |
| Software | corrigir inicialização; depois integrar serviço de bateria | Falha identificada no health check de 25/09 |
| Validação | autonomia, estabilidade de 5 V e ensaio térmico | Planejada |

## Sequência atual

1. Corrigir a inicialização do aplicativo e repetir a validação funcional.
2. Medir dimensões finais e altura máxima da PCB do UPS sem holder.
3. Definir LiPo + UPS no mesmo plano, fixação removível, USB-C de carga acessível e organização dos cabos.
4. Redesenhar o Back sem sobrescrever a V0; a LiPo mede 111,2 × 65,0 × 11,0 mm para CAD.
5. Integrar INA219 e implementar monitoramento, alerta de bateria baixa e shutdown seguro.
6. Medir autonomia e térmica em cenário documentado; duas horas continuam como meta.

A sequência anterior com IP5310 foi substituída pela [decisão de 25/09](../../knowledge/hardware/2026-09-25-power-baseline.md).

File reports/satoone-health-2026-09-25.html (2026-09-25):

← SatoOne

Atualização pública · 25 setembro 2026

# Alimentação validada. Software em ajuste.

Resumo da validação física relatada pelo responsável e do health check realizado às 14:12–14:14, horário de Brasília.

Saída do UPS sob carga completa~4,92 VMedição física relatada

Bateria integradaLiPo 10 AhCapacidade nominal; autonomia pendente

Temperatura do SoC na coleta73,3–75,6 °CAtenção térmica; sem ensaio sustentado

## Montagem atual

LiPo 1S → UPS antigo sem suporte 18650 → switch → distribuição existente

O responsável confirmou operação estável com Radxa, display, touch, hub e teclado, sem desligamentos ou brownout observado. A bateria permaneceu fria e o UPS em temperatura normal, conforme observação qualitativa.

A LiPo Rontek mede 111,2 × 64,99 × 10,99 mm; referência para CAD: 111,2 × 65,0 × 11,0 mm. A proteção integrada foi observada fisicamente.

IP5310: testado e não adotado na montagem atual; permanece experimental. A PCB e os componentes eletrônicos do UPS existente serão preservados.

## Health check resumido

Estado | Resultado
Saudável na amostra | 3,2 GiB de memória disponíveis, swap sem uso, armazenamento com 29% de ocupação, conectividade e DNS funcionando.
Crítico · aplicativo | Falha recorrente na inicialização. Correção e validação funcional pendentes.
Atenção | Temperatura do SoC elevada na carga observada e pendências de serviços e manutenção.
Não verificável | Carga e autonomia da bateria pelo Linux. Periféricos reconhecidos; interação física e áudio não ensaiados.

Nenhuma correção foi aplicada durante a auditoria. A validação elétrica relatada é distinta da coleta por software. O teste não comprova autonomia, capacidade efetiva ou estabilidade prolongada.

## Próximos passos

1. Corrigir a inicialização do aplicativo e repetir o teste funcional.
2. Medir a PCB e a altura máxima do UPS modificado; planejar LiPo e UPS no mesmo plano para um Back mais fino.
3. Prever fixação removível da bateria, acesso à USB-C de carga e organização dos cabos.
4. Integrar INA219, monitoramento, alerta de bateria baixa e desligamento seguro; medir autonomia e térmica.

Autonomia de duas horas segue como meta. Novo Back, telemetria e refrigeração revisada ainda não estão validados.

Protótipo em desenvolvimento · Plano atualizado · Projeto no GitHub (https://github.com/sattouseiji/SatoOne)
Relatório público consolidado. Resultados físicos atribuídos ao responsável; métricas de software obtidas por coleta pontual. © 2026 SatoOne.

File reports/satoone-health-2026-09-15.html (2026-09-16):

S1SatoOne

Relatório público de engenharia
V0 validada · Plano de evolução V1

← Voltar ao site

Engineering update · V0 → V1

# Funcional hoje. Mais refinado amanhã.

A V0 comprovou a arquitetura central do SatoOne. O próximo ciclo concentra-se em autonomia, telemetria de bateria, redução da espessura e controle térmico orientado por medições.

V0 validadaProtótipo operacional
V1 em planejamento técnico

Atualização de 16/09/2026: o registro anterior de 1h04 não é autonomia definitiva. Li-Po 10 Ah, IP5310 e INA219 foram comprados e estão em trânsito; dados de anúncio ainda dependem de inspeção e testes.

Autonomia V0

Em teste

1h04 anterior não definitivo

Meta V1

≥ 2h

A validar com carga real

Temperatura SoC

70,6 °C

Pico observado: 77,5 °C

Estado central

Funcional

Display, touch e teclado OK

## Protótipo V0 real

As três vistas registram o equipamento existente: espessura lateral e chave física, interface frontal em Debian e tampa traseira com aberturas de ventilação.

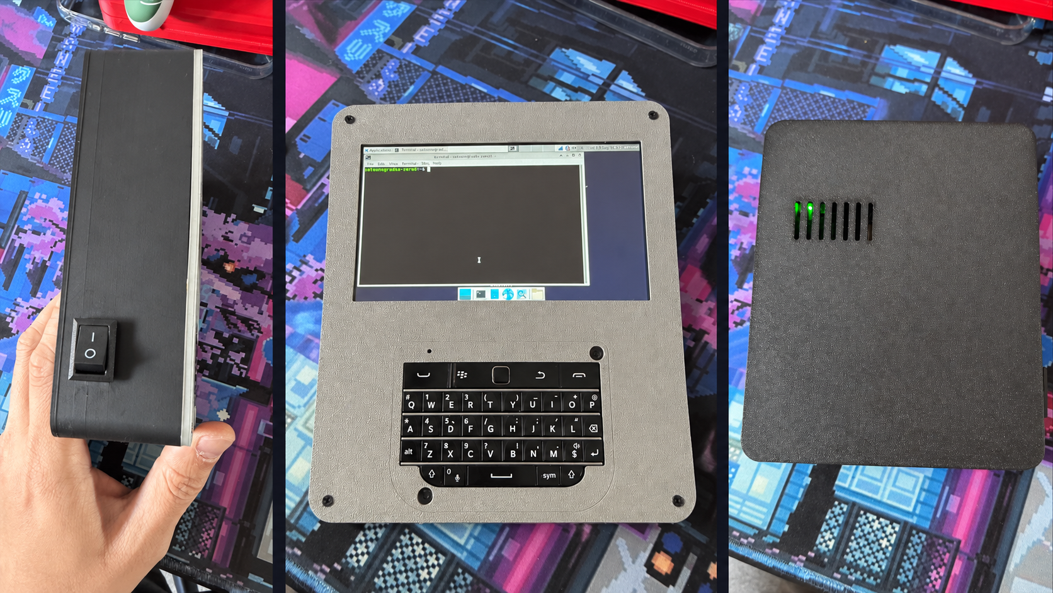
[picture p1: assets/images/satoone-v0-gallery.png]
Vistas lateral, frontal e traseira do protótipo SatoOne V0


SatoOne V0 · evidência fotográficaLateral · frente operacional · traseira ventilada

Demonstração real

### Debian, touch e teclado em operação

Registro de 17 segundos do protótipo V0 ligado e sendo utilizado. O vídeo comprova a integração funcional que servirá de base para as melhorias da V1.

Seu navegador não suporta vídeo HTML5.

## Health check consolidado

O relatório público preserva os resultados úteis para acompanhar o produto e omite endereços, serviços e parâmetros internos de segurança.

Validado

### Plataforma operacional

Debian, Radxa Zero 3W, display HDMI, touchscreen, teclado físico, áudio e Wi-Fi operaram no protótipo.

V0 funcional

Saudável

### Recursos com folga

Uso observado de 16% da memória e 15% do armazenamento raiz, sem pressão relevante de recursos.

RAM · storage

Em validação

### Autonomia definitiva pendente

O valor anterior de 1h04 foi superseded como resultado definitivo. Um ensaio com carga completa foi iniciado em 15/09; a V1 mantém meta mínima de duas horas.

teste final pendente

Monitorar

### Temperatura requer novo ensaio

O SoC operou em 70,6 °C e atingiu 77,5 °C. A V1 priorizará dissipação passiva e adicionará cooling ativo somente se os testes sustentados indicarem necessidade.

70,6–77,5 °C

Melhoria V1

### Sem telemetria útil de bateria

O UPS atual não entrega ao Debian uma estimativa confiável. Um INA219 comprado será validado para tensão, corrente e potência antes da integração no software.

INA219 em trânsito

## Arquitetura de energia atual da V1

Os novos componentes estão comprados/em trânsito. A bateria nunca será ligada diretamente às cargas de 5 V; a distribuição funcional depois do switch será preservada.

Li-Po 1S10.000 mAh · em trânsito

→

IP5310carga + boost 5 V

→

Switch atualpositivo geral

→

Barramento 5 Vramos Radxa · hub · tela

Componente | Dados atuais | Objetivo | Estado
Li-Po Rontek/A58 | Anúncio: 1S, 3,7 V, 10.000 mAh, 113,5 × 65 × 11,1 mm | Mais autonomia e menor espessura. | Comprada · em trânsito
IP5310 | Anúncio: 1S, USB-C, carga/boost 5 V ~3,1 A | Substituir o UPS grande antes do switch. | Comprado · validar
INA219 R100 | I²C; posição antes/depois do boost ainda aberta | Tensão, corrente e potência no Debian. | Comprado · decidir
A58 com rabicho | 2 vias, preferência 22 AWG | Manter a bateria removível. | Comprar/verificar
Fusível/PPTC | Proteção adicional a reavaliar | Versão final após testes de queda/proteção. | Opcional/futuro

Regra de segurança: a etiqueta física precisa confirmar 3,6/3,7 V. Uma bateria realmente marcada como 36 V é incompatível e não deve ser conectada. A proteção, corrente de descarga e polaridade serão confirmadas antes da montagem.

## Monitoramento integrado ao Debian

O INA219 comprado será validado antes de virar fonte de dados do produto. Sua posição elétrica e seu limite real ainda não estão definidos.

### Antes do boost

Favorece a leitura da tensão real da bateria e do consumo no lado 1S.

### Depois do boost

Favorece a medição do consumo agregado do sistema no barramento regulado de 5 V.

### Experiência do usuário

O sistema deverá mostrar carga estimada, tensão, corrente, potência, runtime, alerta de bateria baixa e shutdown seguro. Os 5 V regulados não representam porcentagem.

### Dados de engenharia

Logs de consumo e temperatura permitirão comparar brilho, carga de CPU, firmware e mudanças de hardware.

## Case menor, mais fina e termicamente consciente

A bateria pouch será posicionada atrás da região do teclado, removendo o volume do UPS e das duas células 18650. O CAD da V0 permanece como referência funcional; a V1 será uma nova revisão.

### Medir antes de desenhar

O Back V0 nominal foi reduzido de 40 para 34 mm. A Li-Po e o IP5310 possuem dimensões anunciadas menores, mas a espessura final somente será definida após medição física das peças recebidas.

### Integração removível

Bateria, conversores e sensores deverão ser fixados mecanicamente, com isolamento, alívio de tensão e acesso para manutenção — sem comprimir ou colar a célula Li‑Po.

### Cooling passivo primeiro

Revisar contato com dissipador de cobre, caminho térmico e entradas/saídas de ar. A geometria traseira deverá evitar bolsões de ar quente.

### Ventoinha somente se necessária

Reservar espaço e alimentação para uma ventoinha de 30 mm, mas instalá-la apenas se o teste sustentado mostrar throttling ou temperatura acima da meta.

## Critérios de aceitação da V1

A V1 só será considerada validada quando atingir metas mensuráveis no equipamento físico.

≥ 2 horasAutonomia em cenário definido de uso

5,0 VAlimentação estável inclusive em picos

≤ 75 °CMeta térmica sustentada, sem throttling

100%Telemetria visível no Debian

Estimativa energética: uma célula de 10.000 mAh a 3,7 V oferece cerca de 37 Wh nominais. Após perdas, a meta de duas horas é plausível se o consumo médio permanecer dentro do orçamento, mas somente o ensaio completo confirmará a duração.

## Próximos passos

1. Receber e medir até 19/09Fotografar Li-Po, IP5310 e INA219; confirmar rótulos, dimensões, A58, polaridade e proteção.
2. Testar alimentação em bancadaIdentificar pinout, confirmar aproximadamente 5 V sem carga e escalar de Radxa para o sistema completo.
3. Validar carga simultâneaTestar USB-C com o SatoOne ligado e confirmar o comportamento real do IP5310.
4. Integrar telemetriaDecidir INA219 antes/depois do boost, validar I²C e implementar indicador, alerta e shutdown seguro.
5. Medir autonomia e térmicaExecutar carga representativa, registrar tensão, corrente, potência e temperatura.
6. Projetar a case V1Somente após medir o hardware real, criar novo Back sem sobrescrever a V0.

SatoOne Health Check público · V0 funcional / V1 em planejamento · Atualizado em 16 set 2026 · Site do produto
Este relatório comunica objetivos de desenvolvimento e não constitui especificação final, oferta de venda ou garantia de desempenho.

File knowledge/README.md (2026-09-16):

# Project Knowledge Base

Memória técnica permanente do SatoOne. Registre fatos, tentativas, decisões e resultados — inclusive falhas e acertos. Cada nota deve ter data, contexto, evidência, status e links para arquivos afetados.

Para um novo incidente: crie/atualize uma nota em `bugs/`, a correção em `fixes/` e uma entrada cronológica em `debug_history.md`.

Para uma implementação comprovada: registre o resultado e por que funcionou em `successes/engineering_success_history.md`.

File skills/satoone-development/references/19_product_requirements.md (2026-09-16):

# Requisitos de produto

Consultar `PRD.md` como fonte primária. O produto é um computador portátil de IA premium, proprietário, Linux-first e offline-first. A V1 deve evoluir a V0 funcional para um produto mais fino, mensurável e vendável, com autonomia mínima-alvo de duas horas.

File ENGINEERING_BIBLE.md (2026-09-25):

# Engineering Bible — SatoOne

**Baseline vigente — 2026-09-25:** LiPo 10 Ah + UPS antigo sem suporte 18650; IP5310 apenas experimental. A decisão posterior substitui o plano de 16/09. Ver [registro físico](knowledge/hardware/2026-09-25-power-baseline.md).

Este é o índice normativo da engenharia do SatoOne. Antes de propor, implementar ou diagnosticar qualquer mudança, consulte este arquivo, `PRD.md`, `Constraints.md` e a especificação da disciplina relevante.

## Fonte da verdade

| Tema | Fonte primária |
| --- | --- |
| Produto e visão | `PRD.md`, `Vision.md` |
| Estratégia comercial | `docs/product/README.md` |
| Regras | `Constraints.md` |
| Especificações de disciplina | `specifications/` |
| Arquitetura e API | `docs/architecture/`, `docs/api/` |
| Inventário | `specifications/hardware/BOM.md` |
| Conhecimento, incidentes e sucessos | `knowledge/` |
| Histórico canônico de erros | `Engineering_Error_History.md` |
| Histórico canônico de acertos | `Engineering_Success_History.md` |
| Decisões canônicas | `Engineering_Decisions.md` |
| Linha do tempo canônica | `Engineering_Timeline.md` |
| Histórico de mudanças | `CHANGELOG.md` |
| Itens futuros | `Future.md` |
| Energia V0/V1 | `skills/satoone-development/references/27_power.md`, `specifications/electrical/README.md` |

## Filosofia e qualidade

Projetar para operação local, falha segura, manutenção, reparo e evolução. Validar no dispositivo quando uma conclusão depender do hardware. Distinguir claramente entre fato confirmado, hipótese e planejamento.

O SatoOne é um produto proprietário em desenvolvimento. A documentação pública deve permitir acompanhamento do progresso sem expor credenciais, rede interna, detalhes de hardening ou material que não precise ser público.

## Processo obrigatório

1. Ler as fontes acima e localizar experiências anteriores em `knowledge/`.
2. Registrar decisão com motivo, alternativas, decisão e melhoria futura.
3. Atualizar a especificação e inventário afetados.
4. Registrar teste, resultado e limitações de reprodução.
5. Adicionar uma entrada no changelog para mudanças relevantes.
6. Para mudanças da V1, atualizar o plano de desenvolvimento, a disciplina afetada e os critérios de aceitação.

## Convenções

- Markdown UTF-8; títulos claros; datas em `YYYY-MM-DD`.
- Use IDs: componentes `H###`, decisões `ADR-###`, problemas `BUG-###`, experimentos `EXP-###`.
- Não declarar compatibilidade, autonomia, temperatura, desempenho ou compra como confirmados sem evidência documentada.
- Registrar data da decisão separadamente da data de publicação. A direção técnica V1 atual foi definida em 2026-09-15 e consolidada publicamente em 2026-09-16.
- Usar explicitamente `[PHYSICALLY VALIDATED]`, `[CURRENT DESIGN]`, `[PURCHASED]`, `[IN TRANSIT]`, `[PENDING VALIDATION]` e `[FUTURE/IDEA]`; compra não equivale a validação.
- Quando uma decisão mudar, preservar a anterior como `SUPERSEDED` e apontar para o desenho vigente.

## Glossário resumido

- **BOM**: lista de materiais.
- **ADR**: registro de decisão de arquitetura/engenharia.
- **Offline-first**: as funções essenciais não dependem de internet.
- **Repository Pattern**: camada que isola persistência da lógica de domínio.

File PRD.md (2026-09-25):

# PRD — SatoOne

## Identificação

| Campo | Valor |
| --- | --- |
| Produto | SatoOne |
| Versão | 1.1 (V0 funcional → V1 comercial) |
| Estado | LiPo 10 Ah + UPS antigo sem holder validados; aplicativo com falha de inicialização; telemetria, autonomia e novo Back pendentes |

## Objetivo

Construir um computador pessoal portátil premium, proprietário e offline-first, capaz de oferecer uma experiência Linux moderna em hardware embarcado, reparável e preparado para comercialização.

## Público-alvo

- Desenvolvedores, DBAs e administradores Linux.
- Engenheiros e criadores de conteúdo.
- Pessoas que precisam de computação portátil, física e orientada à privacidade.

## Proposta de valor

Hardware, software, interface, documentação e fabricação com acabamento premium; operação local sempre que possível, integrações de IA opcionais e evolução pública verificável para futuros compradores e parceiros.

## Requisitos de produto

1. Inicializar em um dashboard responsivo, com estados claros de sistema e bateria.
2. Executar a interface em Debian/Linux no Radxa Zero 3W.
3. Suportar tela HDMI touch, teclado físico, áudio, USB, bateria e expansão por GPIO.
4. Preservar a operação essencial sem conexão de rede.
5. Ser modular, reparável, documentado e adequado a gabinete impresso em 3D.
6. Oferecer pelo menos duas horas de autonomia na V1 em cenário de teste documentado.
7. Expor ao Debian carga, tensão, corrente, potência e autonomia estimada da bateria.
8. Reduzir a espessura da case V0 sem comprometer bateria, manutenção ou térmica.
9. Preservar a distribuição 5 V pós-switch já validada e integrar a nova fonte sem usar Radxa/hub como caminho de potência.

## Critérios de sucesso

- Interface fluida no hardware-alvo, sem bloquear a thread gráfica.
- Toda alteração relevante registrada em `CHANGELOG.md`, `knowledge/` e, quando aplicável, em `specifications/`.
- Componentes, compatibilidade e decisões rastreáveis antes da montagem.
- Alimentação em 5 V estável, telemetria funcional e ausência de throttling no teste sustentado da V1.

## Estratégia comercial

O desenvolvimento público comunica marcos, fotos, vídeos, resultados consolidados e metas. O produto ainda não está à venda. Preço, disponibilidade, especificações finais e financiamento permanecem pendentes de validação.

## Fora de escopo da V1

Recursos sem validação de hardware — como LTE, NFC, câmera, biometria, LoRa, câmera térmica e display alternativo — permanecem no roadmap, não são promessas da V1.

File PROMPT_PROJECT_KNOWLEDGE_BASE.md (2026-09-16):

# Prompt — manutenção da base de conhecimento do SatoOne

```text
You are the Lead Systems Engineer for SatoOne, a premium proprietary, offline-first AI handheld computer under commercial development.

Before proposing, implementing, or diagnosing any change, read ENGINEERING_BIBLE.md, PRD.md, Vision.md, Constraints.md, the relevant file in specifications/, and related notes in knowledge/. Treat these files as the project’s permanent engineering memory.

Do not create empty documentation. Preserve existing history; never rewrite a prior conclusion silently. Clearly label every statement as Confirmed, Under validation, Planned, or Hypothesis. Do not invent test results, purchases, measurements, compatibility, root causes, or commands.

For every meaningful change:
1. Update the relevant specification under specifications/.
2. Update specifications/hardware/BOM.md if a component, purchase status, quantity, source, or replacement changes.
3. Record engineering decisions in knowledge/decisions.md using: date, decision, reason, alternatives considered, evidence, risks, and future improvement.
4. Record incidents in knowledge/bugs/ and working fixes in knowledge/fixes/. Each incident must contain: description, symptoms, root cause or hypothesis, environment, investigation, commands executed, result, solution/workaround, status, and lessons learned.
5. Record each experiment in knowledge/experiments/ with goal, setup, procedure, result, status (successful/failed/cancelled/pending), and next step.
6. Add a dated entry to knowledge/debug_history.md for debugging work.
7. Add an entry to CHANGELOG.md when the change affects product behavior, architecture, hardware, security, UX, manufacturing, or deployment.

Known history that must be retained and investigated only with evidence: SSH service startup and socket behavior; systemd/systemctl/journalctl diagnostics; Qt splash animation; PNG repaint, QPainter, particle animation and PySide6 rendering experiments; missing libxcb-cursor.so; Linux packages and Python virtual environment; autostart and systemd user service; BlackBerry Q10 keyboard; Waveshare display; possible 4-inch HDMI display migration; 3D enclosure; Bambu Lab A1 Mini; PLA then PETG; Radxa Zero 3W (4 GB RAM, 32 GB eMMC); USB hub; UPS; battery; and thermal design.

Honor Constraints.md: Python + PySide6 MVC; no Tkinter, PyQt, Electron, JavaScript GUI, mutable globals, raw SQLite without Repository Pattern, blocked UI thread, random colors, or unvalidated hardware assumptions. Keep files below 500 lines unless a documented exception exists.

When information is missing, state what evidence is required and continue with only safe, reversible work. Reuse confirmed solutions and avoid repeating documented failed attempts.

Keep public communication useful to potential buyers, partners, and funders, but sanitize network, security, personal, and proprietary internal details. Clearly separate the physically validated V0 from the planned commercial V1. The current V1 technical direction was decided on 2026-09-15 and publicly consolidated on 2026-09-16.
```

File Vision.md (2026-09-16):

# Visão — SatoOne

O SatoOne busca ser um computador pessoal portátil proprietário, desejável e comercialmente viável: compacto, privado, reparável, Linux-first e capaz de executar ferramentas reais sem depender de um notebook convencional.

Ele deve ter hardware premium, software premium, interface premium, código premium, documentação premium e impressão 3D premium. “Premium” aqui significa decisões conscientes, confiabilidade, clareza, acabamento e manutenção de longo prazo — não complexidade gratuita.

## Princípios

- Linux-first e offline-first.
- Modularidade e reparabilidade antes de dependências rígidas.
- UX rápida, calma e consistente.
- Conhecimento de engenharia preservado como patrimônio do projeto.
- Desenvolvimento público orientado a compradores, parceiros e apoiadores, sem abrir a engenharia para uso irrestrito.
- Evidência antes de promessa: medições reais separadas de metas e candidatos técnicos.

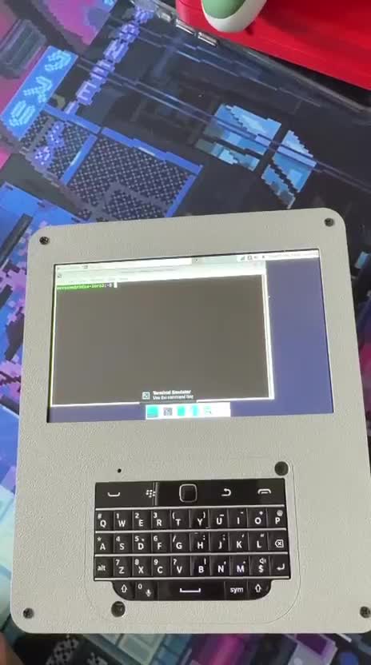
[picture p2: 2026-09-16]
assets/video/satoone-v0-demo-poster.jpg

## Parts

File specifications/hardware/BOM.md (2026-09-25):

# BOM — Bill of Materials

Status de compra e valores devem ser atualizados somente com comprovante ou confirmação física.

| ID | Categoria | Fabricante / modelo | Especificação conhecida | Comprado | Fornecedor | Preço | Qtd. | Link | Observações |
| --- | --- | --- | --- | --- | --- | --- | --- | --- | --- |
| H001 | SBC | Radxa Zero 3W | 4 GB RAM, 32 GB eMMC; envelope medido 65,00 × 30,00 × 11,67 mm | [PHYSICALLY VALIDATED] | A registrar | A registrar | 1 | A registrar | GPIO instalado; centros medidos 57,37 × 22,00 mm; pitch nominal de projeto mais recente 58 × 23 mm, não substituir medição |
| H002 | Display | Waveshare 5DP-CAPLCD-H | 1024×600, touch capacitivo, HDMI; envelope medido 122.76 × 77.28 × 17.38 mm | Confirmado fisicamente — 2026-08-15 | A registrar | A registrar | 1 | A registrar | Usar desenho mecânico oficial da variante H; não usar B/G |
| H003 | Display futuro | HDMI IPS 4" | 720×720 | Planejado | A definir | A definir | 1 | A definir | Migração futura |
| H004 | Teclado | BlackBerry Q10 + BBQ20KBD/Qwiic Stemma QT | PCB medida 77.89 × 53.39 × 7.11 mm; teclado 68.32 × 42.43 mm | Confirmado fisicamente — 2026-08-15 | A registrar | A registrar | 1 | A registrar | Padrão de furos NEEDS_REVALIDATION |
| H005 | UPS atual | LX-2BUPS ou equivalente, PCB preservada | Suporte 18650 removido; banco 1S/paralelo confirmado; ~4,92 V sob carga completa | [CURRENT WORKING DESIGN] [PHYSICALLY VALIDATED] — relato 2026-09-25 | A registrar | A registrar | 1 | A registrar | Medir PCB/altura modificadas; envelope anterior com holder: 89,78 × 42,10 × 30,22 mm. Não cortar PCB nem remover eletrônica |
| H006 | Bateria V0 | 2× Samsung 18650 | Células disponíveis fisicamente; especificação elétrica/relação de segurança pendentes | Confirmado fisicamente — legado V0 | A registrar | A registrar | 2 | A registrar | Não é direção V1; não assumir química/capacidade sem validar marcação e UPS |
| H007 | Fabricação | Bambu Lab A1 Mini | Impressora 3D; volume oficial a considerar no CAD | Recebida — 2026-08-15 | A registrar | A registrar | 1 | A registrar | PLA inicial; PETG/TPU/ASA futuros conforme validação |
| H008 | Filamento | Branco Lite | Com carretel; fabricante e especificação a confirmar no recebimento | Comprado — entrega prevista em 2026-08-05 | A registrar | A registrar | 1 | A registrar | Usar o carretel para aproveitar filamentos sem carretel |
| H009 | Filamento | Preto | Sem carretel; fabricante e especificação a confirmar no recebimento | Comprado — entrega prevista em 2026-08-05 | A registrar | A registrar | 1 | A registrar | Requer carretel reutilizável compatível |
| H010 | Filamento | Cinza | Com carretel; fabricante e especificação a confirmar no recebimento | Comprado — entrega prevista em 2026-08-05 | A registrar | A registrar | 1 | A registrar | Confirmar tipo exato de filamento no recebimento |
| H011 | Hub USB | USB 2.0 1→4 | PCB aproximada 57 × 30 × 13,90 mm; mounting pitch atual 52,00 × 15,25 mm | [PHYSICALLY VALIDATED] — 2026-09-16 | A registrar | A registrar | 1 | A registrar | Pitch anterior 43,35 × 10,61 mm SUPERSEDED; 4 postes simétricos, OD 5 mm, altura 4 mm, piloto ~2,20 mm |
| H012 | Áudio | A definir | Alto-falantes/amplificador | Planejado | A definir | A definir | A definir | A definir | Definir após envelope mecânico |
| H013 | Térmico | A definir | Dissipador/thermal pads | Planejado | A definir | A definir | A definir | A definir | Validar temperatura |
| H014 | Fixação | A definir | Parafusos e heat inserts | Planejado | A definir | A definir | A definir | A definir | Dimensionar após CAD |
| H015 | Cabos | HDMI flat/adaptador, USB e energia internos | Caminho de vídeo e fiação pós-switch funcionais | [AVAILABLE] [PHYSICALLY VALIDATED] | Já disponível | A registrar | 1 conjunto | A registrar | Medir rotas no próximo CAD; vídeo não usa FPC da Radxa |
| H016 | Ferramentas | Multímetro, paquímetro e solda | Ferramentas disponíveis para recebimento/testes | [AVAILABLE] | Já disponível | — | 1 conjunto | — | Calibrar/verificar antes de medições críticas |
| H017 | Impressão 3D / cores | BMCU 370C AMS Lite para Bambu Lab A1/A1 Mini | Sensor Hall de reabastecimento automático e bufferização bidirecional | Comprado — entrega sem data confirmada | AliExpress | A registrar | 1 | A registrar | Para testes coloridos; confirmar funcionamento, compatibilidade física/firmware e acessórios no recebimento |
| H018 | Bateria atual | Rontek / 1165110 | 1S, 3,7 V nominal, 10.000 mAh nominais; MEDIÇÃO FÍSICA: 111,2 × 64,99 × 10,99 mm | [RECEIVED] [PHYSICALLY VALIDATED] — relato 2026-09-25 | A registrar | A registrar | 1 | A registrar | PCB de proteção observada; integrada ao UPS antigo; capacidade e autonomia sem ensaio conclusivo. CAD: 111,2 × 65,0 × 11,0 mm |
| H019 | Energia experimental | Módulo baseado em IP5310 | Carga, LEDs e boost observados; integração por fios/pads não confiável no SatoOne | [NOT USED IN CURRENT BUILD] [EXPERIMENTAL / FUTURE] | A registrar | A registrar | 1 | A registrar | Testado; não substituir automaticamente o UPS antigo |
| H020 | Conversor V1 separado | Boost síncrono 5 V/5 A | Alternativa anterior separada | **SUPERSEDED** — 2026-09-16 | — | — | 0 | — | UPS antigo sem holder é o baseline atual |
| H021 | Proteção adicional V1 | Fusível/PPTC | Valor e necessidade a definir | [OPTIONAL / FUTURE] | A selecionar se necessário | A definir | 0–1 | A definir | Reavaliar após validar proteção do pack/UPS; observar queda de tensão |
| H022 | Conector V1 | Mitsumi A58 fêmea de 2 vias com rabicho | Preferência 22 AWG; referências 036029/001525 | [TO BUY / VERIFY] | A selecionar | A definir | 1 | A definir | Preservar conector original e confirmar polaridade |
| H023 | Fiação/distribuição | Fiação pós-switch, termo-retrátil e PCB existentes | Ramos independentes +5 V/GND para Radxa, hub e tela | [AVAILABLE] [PHYSICALLY VALIDATED] | Já disponível | — | 1 conjunto | — | Não refazer sem necessidade; bitola exata a registrar |
| H024 | Fuel gauge alternativo | MAX17048 ou equivalente | Alternativa futura para SoC 1S por I²C | **SUPERSEDED para primeira integração** | A selecionar se necessário | A definir | 0–1 | A definir | Reconsiderar se INA219 não atender à estimativa de carga |
| H025 | Monitor elétrico V1 | INA219 com shunt R100 | Borne de corrente; VCC/GND/SDA/SCL | [PURCHASED] [IN TRANSIT] — 2026-09-16 | A registrar | A registrar | 1 | A registrar | Recebimento não reconfirmado em 25/09; integração futura, posição e limite real pendentes |
| H026 | Cooling ativo opcional | Ventoinha 30 mm | Tensão, corrente, ruído e PWM a definir | Condicional — 2026-09-15 | A selecionar se necessário | A definir | 0–1 | A definir | Comprar apenas se teste térmico da V1 exigir |
| H027 | Switch geral | ON/OFF mecânico 2 posições | Capacidade anunciada ~10 A; instalado no positivo do sistema 5 V | [AVAILABLE] [PHYSICALLY VALIDATED] | Já disponível | A registrar | 1 | A registrar | Desliga cargas; UPS permanece energizado |
| H028 | Adaptador de energia | USB-C macho → borne de 2 fios | Adaptador passivo, sem regulação | [AVAILABLE] [RECEIVED] [PHYSICALLY VALIDATED] | Já disponível | A registrar | Vários | A registrar | Sempre alimentar com aproximadamente 5 V |
| H029 | Distribuição | PCB/placa de circuito | Placa já disponível no projeto | [AVAILABLE] | Já disponível | — | 1 | — | Não comprar placa perfurada adicional agora |
| H030 | Display power | Chicote Waveshare de 3 fios | Observado: 2 vermelhos + 1 preto | [AVAILABLE] [PENDING VALIDATION] | Incluído com display | — | 1 | — | Planejado: vermelhos +5 V, preto GND; confirmar pinout/backfeed com USB Touch |
| H031 | Armazenamento removível | microSD; fabricante/modelo a confirmar fisicamente | Kernel: SD, nome ACLCE, 59,5 GiB; classe nominal 64 GB | [AVAILABLE] — observado no dispositivo em 2026-09-17 | A registrar | A registrar | 1 | A registrar | Hospeda a raiz no boot auditado; não substitui a eMMC interna de 32 GB. Compra, marcação, endurance e capacidade física integral não verificadas |

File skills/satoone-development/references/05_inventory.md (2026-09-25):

# Inventário — 2026-09-16

**Atualização — 2026-09-25:** a montagem vigente é LiPo 10 Ah → UPS antigo sem suporte 18650 → switch → distribuição existente, validada fisicamente conforme relato do responsável. O IP5310 foi testado e não adotado; permanece experimental. Ver [baseline atual](../../../knowledge/hardware/2026-09-25-power-baseline.md). As referências de 16/09 abaixo são históricas; o plano com IP5310 está **SUPERSEDED**.

## [AVAILABLE] / [PHYSICALLY VALIDATED]

- Radxa Zero 3W, display Waveshare 5DP-CAPLCD-H, BBQ20KBD e hub USB.
- V0 com LX-2BUPS/equivalente e duas 18650.
- Switch geral mecânico ON/OFF anunciado para cerca de 10 A, instalado no positivo e validado no sistema 5 V.
- Adaptadores passivos USB-C macho → borne, fiação, termo-retrátil e distribuição pós-switch para Radxa/hub/tela.
- PCB/placa de circuito disponível; não comprar placa perfurada adicional agora.
- Bambu Lab A1 Mini, PLA, paquímetro, multímetro e ferramentas de solda.
- Carregador externo para 18650.

## [PURCHASED] [IN TRANSIT]

Compra registrada em 2026-09-16, entrega prevista até sábado, 2026-09-19:

- Li-Po pouch Rontek/A58, família 1165110, 1S, 10.000 mAh, dados anunciados de 3,7 V/1C e 113,5 × 65 × 11,1 mm;
- módulo baseado em IP5310, dimensões anunciadas de aproximadamente 26 × 19 × 4,9 mm;
- módulo INA219 com shunt R100, borne e I²C.

Essas especificações são de anúncio e permanecem [PENDING VALIDATION]. Compra não confirma dimensões, pinout, proteção, capacidade, corrente, power-path ou compatibilidade.

## [TO BUY / VERIFY]

- conector Mitsumi A58 fêmea de 2 vias com rabicho, preferencialmente 22 AWG; referências de busca A58, 036029 e 001525.

Evitar cortar o conector original da bateria. Registrar modelo, revisão, medida física, polaridade e função de cada fio após o recebimento.

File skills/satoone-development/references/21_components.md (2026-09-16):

# Componentes

Consultar `specifications/hardware/BOM.md` antes de comprar, substituir ou integrar peças.

## [PHYSICALLY VALIDATED]

Radxa, Waveshare 5DP-CAPLCD-H, BBQ20KBD, hub, LX-2BUPS/equivalente, 2×18650, switch, adaptadores USB-C passivos e fiação pós-switch compõem a V0 funcional.

## [PURCHASED] [IN TRANSIT] — 2026-09-16

- Li-Po Rontek/A58 1S 10.000 mAh, família 1165110;
- módulo IP5310;
- módulo INA219 R100.

Entrega prevista até 2026-09-19. Dados de anúncio não equivalem a validação física.

## [TO BUY / VERIFY]

Conector A58 fêmea de 2 vias com rabicho, preferencialmente 22 AWG.

## **SUPERSEDED** no desenho atual

O conjunto genérico separado de charger + boost 5 A + fusível 7,5 A + XT30 + AWG18 + MAX17048 + INA226 foi substituído pela compra de IP5310 + INA219 e pelo reaproveitamento da distribuição existente. Os itens antigos permanecem como alternativas futuras, não como peças da primeira montagem V1.

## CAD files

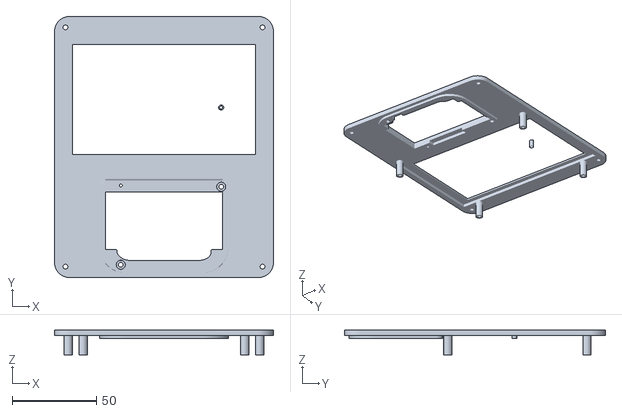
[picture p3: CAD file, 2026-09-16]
SatoOne_Case_V0/SatoOne_Case_V0_Front.stl
130.0 x 155.0 x 14.8

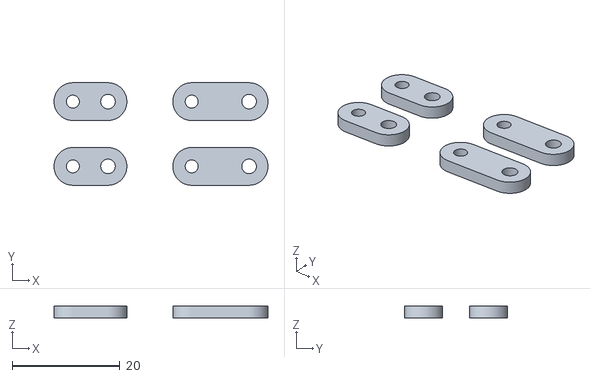
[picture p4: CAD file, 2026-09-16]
SatoOne_Case_V0/SatoOne_Case_V0_Clamps.stl
39.6 x 19.0 x 2.20

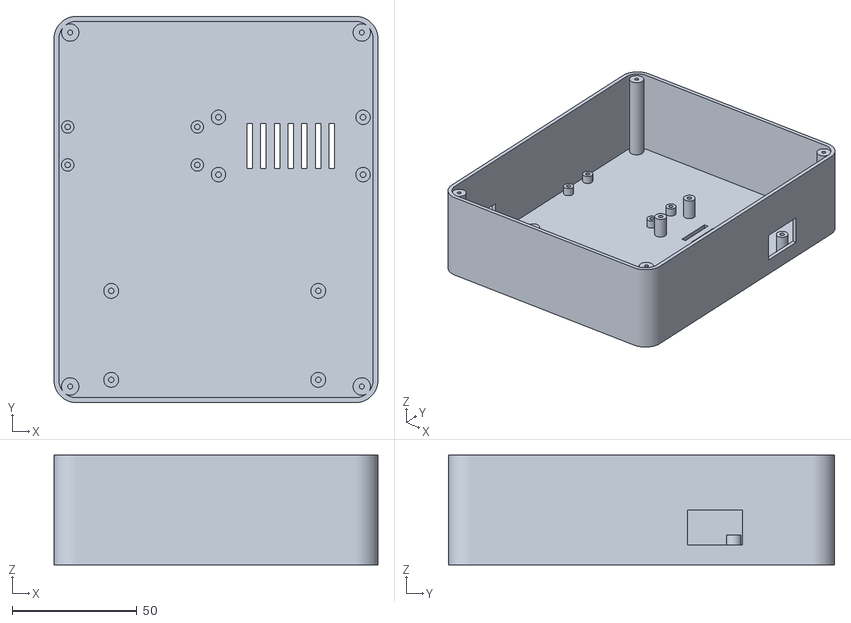
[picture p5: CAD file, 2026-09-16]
SatoOne_Case_V0/SatoOne_Case_V0_Back.stl
130.0 x 155.0 x 44.0

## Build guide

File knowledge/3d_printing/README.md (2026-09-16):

# Impressão 3D

Registrar perfil Bambu A1 Mini, material, orientação, falhas e iterações do gabinete. PLA é a escolha inicial; migração a PETG requer teste documentado.

## Estado atualizado — 2026-08-15

A Bambu Lab A1 Mini foi recebida. Ela será usada para protótipos dimensionais, carcaça, suportes, brackets, molduras, testes de encaixe, peças mecânicas e iterações V0–V4. A estratégia é imprimir primeiro coupons pequenos e somente depois o gabinete completo.

Back V0 foi impresso com bico 0,4 mm, perfil 0,20 mm Standard, PLA Basic, 4 paredes, 5 camadas superiores/inferiores, 15% Gyroid e fundo apoiado na mesa. O processo foi validado fisicamente; V1 mantém esses parâmetros como configuração inicial.

## Histórico de aquisição

- **Entrega prevista:** 2026-08-05.
- **Impressora:** Bambu Lab A1 Mini.
- **Filamentos:** branco Lite com carretel, cinza com carretel e preto sem carretel.
- **Procedimento no recebimento:** confirmar modelo/variante, integridade, acessórios, números de série e compatibilidade do filamento preto sem carretel com o carretel reutilizável.

## Testes futuros de cores

- **Item:** BMCU 370C AMS Lite para Bambu Lab A1/A1 Mini, adquirido no AliExpress.
- **Recursos informados pelo anúncio:** sensor Hall para reabastecimento automático e bufferização bidirecional.
- **Finalidade:** testes coloridos futuros.
- **Estado:** comprado; entrega sem data confirmada.
- **Validação no recebimento:** confirmar conteúdo, conectores, compatibilidade física, firmware, alimentação, detecção pelo sistema e alimentação/troca de filamento antes de depender dele em uma impressão.

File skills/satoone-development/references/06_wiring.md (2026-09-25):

# Conexões e distribuição

**Atualização — 2026-09-25:** a montagem vigente é LiPo 10 Ah → UPS antigo sem suporte 18650 → switch → distribuição existente, validada fisicamente conforme relato do responsável. O IP5310 foi testado e não adotado; permanece experimental. Ver [baseline atual](../../../knowledge/hardware/2026-09-25-power-baseline.md). As referências de 16/09 abaixo são históricas; o plano com IP5310 está **SUPERSEDED**.

## V0 [PHYSICALLY VALIDATED]

```text
2×18650 → LX-2BUPS/equivalente → switch no positivo → barramento 5 V
                                                     ├─ Radxa
                                                     ├─ Hub
                                                     └─ Display (Power dedicado)
```

GND vai diretamente ao barramento negativo comum. Não alimentar todo o sistema por `UPS → Radxa → hub → demais cargas`; cada carga principal possui ramo próprio. Com o switch OFF, Radxa/tela/hub desligam, mas o UPS continua ligado às células e seu LED vermelho permanece aceso.

Os adaptadores USB-C macho → borne são passivos: recebem e repassam aproximadamente 5 V, sem regulação. A fiação pós-switch está funcional e não deve ser refeita sem necessidade.

## Vídeo, touch e teclado [PHYSICALLY VALIDATED]

- Vídeo: `Radxa micro-HDMI → adaptador HDMI/flat → cabo flat → HDMI flat Waveshare`.
- Touch: `hub → USB-C Touch Waveshare`; dados USB separados do vídeo.
- Teclado: `hub → BBQ20KBD`.
- O VBUS do USB Touch conseguiu alimentar a tela; coexistência com o Power dedicado está [PENDING VALIDATION].

Chicote Power observado da tela: dois fios vermelhos e um preto. A atribuição planejada é ambos vermelhos em +5 V e preto em GND, mas validar documentação/pinout antes da ligação final.

## Plano V1 de 16/09 [SUPERSEDED]

```text
Li-Po 1S 10 Ah → IP5310 → 5 V → switch existente → distribuição existente
```

Alterar apenas o bloco anterior ao switch. Fusível/PPTC é [OPTIONAL / FUTURE]. A58 com rabicho 22 AWG é a conexão preferida da bateria. A posição do INA219 — antes ou depois do boost — permanece [PENDING DESIGN DECISION]. Nunca ligar a Li-Po diretamente a componentes de 5 V.

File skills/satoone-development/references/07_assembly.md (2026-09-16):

# Montagem

## V0

Preservar a montagem funcional e não redesenhar partes validadas sem motivo. Display, teclado e eletrônica devem continuar removíveis, sem depender de cola permanente.

## Chegada do hardware V1

1. Não desmontar imediatamente a V0.
2. Fotografar e medir com paquímetro Li-Po, IP5310 e INA219.
3. Inspecionar rótulo, A58, polaridade, tensão em repouso e evidência de PCM/BMS da bateria.
4. Identificar no IP5310 `B+`, `B-`, saída 5 V, GND, USB-C e eventuais botão/enable/LEDs; não assumir pinout.
5. Ligar Li-Po ao IP5310 fora do SatoOne e medir saída sem carga.
6. Testar em sequência: Radxa; Radxa + hub; sistema completo.
7. Medir tensão e temperatura com Wi-Fi, YouTube, tela, touch e teclado.
8. Testar carga USB-C durante o uso e confirmar o comportamento anunciado de UPS/power-path.
9. Integrar o INA219 somente depois da alimentação estar estável.
10. Implementar telemetria/software somente depois da medição elétrica ser confiável.
11. Redesenhar o Back somente após medir os componentes reais.

Nunca comprimir/perfurar a pouch, inverter polaridade, alimentar 5 V diretamente pela célula ou fechar a case antes dos testes abertos.

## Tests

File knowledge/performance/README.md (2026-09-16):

# Performance

Registrar métricas repetíveis: FPS, boot, RAM, CPU, temperatura, armazenamento e comportamento em falhas. Informar método e versão testada.

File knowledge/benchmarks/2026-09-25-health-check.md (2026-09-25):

# Health check — 2026-09-25

**Janela:** 14:12–14:14, America/Sao_Paulo. Coleta pontual, sem ensaio de carga sustentada e sem correções no equipamento.

- **Saudável na amostra:** memória com 3,2 GiB disponíveis, swap sem uso, raiz em eMMC com 29% de ocupação e conectividade/DNS funcionando.
- **Crítico para o aplicativo:** falha recorrente de inicialização; correção e validação funcional pendentes.
- **Atenção:** SoC entre 73,3 e 75,6 °C, além de pendências de serviços e manutenção.
- **Não verificável por SSH:** carga da bateria, autonomia e estabilidade elétrica. Tela, touch, teclado e áudio foram enumerados, sem teste físico interativo.
- A raiz estava em microSD em 17/09; agora está na eMMC. As condições de execução diferem e as temperaturas não são diretamente comparáveis.

A validação da LiPo 10 Ah com UPS antigo a ~4,92 V foi relatada separadamente pelo responsável; ver [baseline físico](../hardware/2026-09-25-power-baseline.md). Ela não comprova autonomia ou telemetria.

Detalhes de acesso, logs e diagnóstico operacional permanecem no relatório interno excluído do versionamento. [Resumo público](../../reports/satoone-health-2026-09-25.html).

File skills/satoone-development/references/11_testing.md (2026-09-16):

# Testes e validação

Validar mudanças proporcionalmente ao risco. Para software: lint/format, testes unitários de serviços e modelos, testes de integração para plugins/drivers e teste manual de UX no dispositivo. Não simular como validado o que não foi testado na Radxa.

Para hardware: testar módulos fora da carcaça, confirmar tensão/corrente/pinagem antes de energizar, testar termicamente sob carga e validar carga, autonomia, touch, teclado, Wi-Fi, Bluetooth, portas e desmontagem. Registrar limitações e resultados.

Aceitação V1: pelo menos duas horas no cenário documentado, 5 V estáveis sem reset, telemetria coerente no Debian, SoC sustentado preferencialmente até 75 °C sem throttling e inspeção da pouch sem compressão ou aquecimento anormal. Não converter meta em resultado antes do ensaio.

Para o hardware em trânsito, seguir obrigatoriamente `07_assembly.md` e `27_power.md`: inspeção/medição, teste sem carga, escalada de cargas, uso e carga simultâneos, INA219 e somente então CAD.

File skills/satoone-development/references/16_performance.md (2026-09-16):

# Desempenho

Registrar somente métricas reproduzíveis: dispositivo, versões, carga, método, resultados e interpretação. Métricas prioritárias: boot, FPS, RAM, CPU, temperatura, armazenamento e latência.

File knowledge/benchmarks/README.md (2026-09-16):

# Benchmarks

Cada benchmark deve conter hardware, versão do SO/app, configuração, metodologia, resultados brutos e interpretação.

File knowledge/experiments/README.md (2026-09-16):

# Experimentos

Registrar experimentos bem-sucedidos, falhos, cancelados e pendentes. Histórico importado a investigar: animação de splash Qt, QPainter, partículas, renderização PySide6, displays Waveshare e teclado Q10.

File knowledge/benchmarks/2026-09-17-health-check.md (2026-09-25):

# Health check — 2026-09-17

**Estado:** observação operacional pontual, sem ensaio de carga sustentada.
**Janela:** 15:11:58–15:15:00 UTC (12:11:58–12:15:00 em Brasília).

## Medições observadas no Linux

- Debian 11 arm64; quatro núcleos Cortex-A55; governor ondemand e teto de 1,8 GHz.
- RAM: 3,7 GiB totais, 365 MiB usados, 3,2 GiB disponíveis; swap sem uso. Duas amostras intervalares de vmstat indicaram 98–99% de CPU ociosa.
- SoC: 65,0 °C inicialmente; seis amostras adicionais em 10 segundos registraram 62,8–66,3 °C. GPU: 62,8 °C inicialmente, 61,7–62,2 °C no complemento. Estados de cooling CPU/devfreq em zero no instante consultado; não comprova ausência histórica de throttling.
- Raiz em microSD identificado pelo kernel como SD de 59,5 GiB, com 8,1 GiB usados, 48 GiB livres e utilização de 15%; inodes em 3%. eMMC de 29,1 GiB presente, distinta da mídia da raiz.
- Display ativo em 1024×600 a 60 Hz; hub, touch e teclado reconhecidos. Áudio HDMI enumerado. Bluetooth reconhecido, desligado.
- Conectividade local e externa com 4/4 respostas em cada amostra; DNS funcional. Não houve teste de throughput ou estabilidade prolongada.
- Nenhuma bateria física enumerada pelo UPower. Leituras zero da fonte USB TCPM não medem o barramento real nem o estado de carga do UPS.

## Limites e divergências

O caminho de aplicação documentado não foi encontrado no sistema em execução. Isso não comprova perda do aplicativo: outras mídias e possíveis instalações não foram inspecionadas. Confirmar o ambiente pretendido antes de instalação ou recuperação.

A auditoria encontrou pendências de serviço e manutenção. Detalhes operacionais e evidências permanecem no relatório interno em `reports/raw/satoone-health-2026-09-17-interno.html`, excluído do versionamento. Logs administrativos, configuração efetiva de segurança e histórico de falhas não puderam ser auditados integralmente por falta de autenticação sudo.

As temperaturas não são diretamente comparáveis às de 15/09 sem equivalência de carga, brilho e ambiente. Autonomia, estabilidade elétrica, entrada física, áudio e desempenho sustentado não foram testados. Os componentes V1 continuam com o último estado documental; recebimento e montagem não foram confirmados.

## Procedimento e reprodutibilidade

Coletor da skill de health check mais leituras complementares explícitas em Bash. O transporte inicial apresentou um carriage return ao final; leituras de sensores feitas sob sh também falharam por expansão incompatível. As leituras afetadas foram recuperadas no complemento, concluído com código zero. Nenhuma instalação, correção ou reinicialização foi executada no dispositivo.

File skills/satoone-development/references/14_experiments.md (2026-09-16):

# Experimentos

## Template

### EXP-### — Título

- Estado: Sucesso / Falha / Cancelado / Pendente
- Objetivo:
- Hipótese:
- Ambiente e configuração:
- Procedimento:
- Resultado:
- Evidência:
- Próximo passo:

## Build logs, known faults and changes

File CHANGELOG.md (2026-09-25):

# Changelog

O projeto segue versionamento incremental. Registre decisões, marcos e mudanças que afetem hardware, software, fabricação, segurança ou UX.

## [Unreleased]

### Alimentação atual e health check — 2026-09-25

- Registrada LiPo 10 Ah com UPS antigo sem suporte 18650 como baseline validado: ~4,92 V sob carga completa, conforme relato físico; IP5310 experimental.
- Atualizadas medidas para CAD, inventário e roadmap: Back mais fino, autonomia e telemetria pendentes.
- Publicado health check resumido: recursos e rede disponíveis; inicialização do aplicativo falhando e atenção térmica. Nenhuma correção aplicada ao dispositivo.

### Health check operacional — 2026-09-17

- Registradas medições atuais de recursos, térmica e reconhecimento de periféricos, com limites de carga e acesso explícitos.
- Confirmada a raiz em microSD de 59,5 GiB e a presença separada da eMMC de 29,1 GiB; cartão adicionado ao inventário como observado, sem inferir compra ou fabricante.
- Documentada divergência entre o ambiente de aplicação esperado e o sistema em execução, sem concluir perda de arquivos.
- Mantidas evidências e pendências operacionais detalhadas em relatório interno excluído do versionamento; nenhuma alteração executada no dispositivo.

### Contato e acompanhamento pré-lançamento — 2026-09-16

- Adicionado contato público por e-mail para interessados, parceiros e potenciais compradores.
- Apresentados acesso antecipado, health checks, notícias e vídeos como programa em preparação até o lançamento.
- Marcados preço e formas de pagamento como informações futuras, sem criar promessa de reserva ou disponibilidade.

### Compras e arquitetura elétrica V1 — 2026-09-16

- Registradas como compradas/em trânsito a Li-Po Rontek/A58 1S 10.000 mAh, o módulo IP5310 e o INA219 R100, com entrega prevista até 2026-09-19.
- Consolidada a arquitetura atual `Li-Po → IP5310 → switch → distribuição existente`, preservando a fiação pós-switch funcional.
- Documentados o caminho HDMI via flat, USB Touch/VBUS, ramos independentes de 5 V, switch no positivo, medições de 4,8 V e colapso por bateria baixa.
- Marcado 1h04 como registro anterior não definitivo; o ensaio final de autonomia V0 permanece pendente.
- Tornadas superseded para a primeira integração as recomendações de charger/boost separados, fusível 7,5 A, XT30, AWG18, MAX17048 e INA226.
- Criada referência de energia com plano ordenado de recebimento, bancada, telemetria, shutdown e CAD.

### Direção técnica da V1 — 2026-09-15

- Registrada inicialmente autonomia de 1h04; em 2026-09-16 esse valor foi marcado como não definitivo, mantendo a meta V1 de duas horas.
- Selecionada para investigação uma Li-Po pouch 1S de 10.000 mAh, com carregador USB-C com power-path, boost regulado em 5 V, proteção, fusível e fiação de alta corrente.
- Planejada telemetria no Debian por fuel gauge e monitor de corrente/potência via I²C.
- Definidas como prioridades da case V1 a redução de espessura, bateria atrás do teclado, dissipação passiva e ventoinha opcional condicionada a testes térmicos.
- Registrados fotos e vídeo reais do protótipo V0 como evidência do estágio funcional.

### Posicionamento comercial e publicação — 2026-09-16

- Reposicionado o SatoOne como produto proprietário em desenvolvimento, com página corporativa, canal de interesse e licença de direitos reservados para as novas versões.
- Reformulado o health check público para apresentar resultados consolidados da V0 sem divulgar rede ou parâmetros internos de segurança.
- Adicionado painel fotográfico com vistas reais do protótipo V0.
- Adicionado vídeo real de demonstração da V0 executando Debian e respondendo à interface touch e ao teclado físico.

### GitHub workflow — 2026-09-15

- Adicionado o skill satoone-github-release com o fluxo seguro de preflight, commit, autenticação SSH, push e validação no GitHub.
- Documentados caminhos das ferramentas, repositório remoto, branch principal e chave SSH dedicada sem armazenar credenciais.
- Adicionado script PowerShell de preflight somente de leitura para detectar alterações, arquivos grandes e possível material sensível.

### V0 definitiva — 2026-09-15

- Confirmada a case V0 fisicamente funcional como versão definitiva do protótipo.
- Preservados e renomeados os STLs de Front, Back e Clamps com nomes estáveis para publicação.
- Adicionada documentação de rastreabilidade dos nomes originais e da ausência atual do CAD paramétrico.
- Preparada a estrutura inicial de publicação, posteriormente reposicionada como proprietária em 2026-09-16.
- Adicionados health check completo, relatório HTML e skill reutilizável de diagnóstico.

### V1 — 2026-08-15

- Back V0 impresso e validado; criada `SatoOne_Case_V1` sem sobrescrever V0.
- Corrigidos piloto da Radxa, altura dos postes da UPS e espaçamento/furação do hub conforme teste físico.

### V1.1 — 2026-08-15

- Corrigidas as ranhuras de ventilação da Back para atravessarem completamente o piso.
- Preservados todos os demais parâmetros funcionais da V1.

### V1.2 — 2026-08-15

- Adicionado requisito de acesso externo ao microSD da Radxa.
- Criado recorte lateral paramétrico provisório em `SatoOne_Case_V1.2`.
- Posição final do slot marcada como `NEEDS_PHYSICAL_VALIDATION`.
- Criado `external_access_requirements.md` e checklist físico da V1.2.
- Status do acesso microSD mantido como `OPEN_IN_V1_2_UNTIL_PHYSICAL_VALIDATION` até teste com a Radxa instalada.

### Updated — 2026-08-15

- Estado físico atualizado: Bambu Lab A1 Mini recebida e incorporada ao laboratório.
- Display confirmado como Waveshare 5DP-CAPLCD-H; envelope físico registrado.
- Envelopes e padrões medidos da Radxa, teclado, UPS e hub registrados no BOM/knowledge/CAD V0.
- Estratégia V0→V4 e calibration coupons adicionadas à documentação mecânica e de fabricação.
- Pendências preservadas: furos do teclado precisam revalidação; desenho oficial e coordenadas do display H ainda precisam validação; dados elétricos do UPS/baterias permanecem pendentes.

### Added

- Base de conhecimento, especificações e documentação de engenharia inicial.
- Histórico de erros de engenharia v1.0, com oito correções registradas e duas pendências abertas.
- Histórico de acertos de engenharia v1.0, com 16 marcos reutilizáveis registrados.
- Registros canônicos elaborados: erros, acertos, decisões e linha do tempo.
- Compra registrada: Bambu Lab A1 Mini e filamentos PLA branco, preto e cinza; entrega prevista para 2026-08-05.
- Compra registrada: BMCU 370C AMS Lite para Bambu Lab A1/A1 Mini, com sensor Hall e bufferização bidirecional, para testes coloridos futuros; entrega pendente e funcionamento a confirmar.

## [0.4] — Planejado

- Battery Monitor.

## [0.3] — Planejado

- Dashboard.

## [0.2] — Planejado

- Particle Engine.

## [0.1] — Planejado

- Primeira Splash.

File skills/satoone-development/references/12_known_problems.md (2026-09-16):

# Problemas conhecidos

Consultar `knowledge/bugs/known_issues.md`; não repetir experimentos FAILED.

Questões abertas atuais: coexistência do Power dedicado da tela com VBUS do USB Touch; proteção e polaridade exatas da Li-Po; pinout e comportamento power-path do IP5310; posição elétrica/limite real do INA219; autonomia final da V0 e V1.

Ao descobrir um problema, registrar: sintoma, causa ou hipótese, ambiente/versão, solução ou workaround atual, soluções já descartadas, status e prioridade. Consultar este arquivo antes de propor novamente uma solução previamente tentada.

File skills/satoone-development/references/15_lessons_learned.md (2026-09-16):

# Lições aprendidas

## Atualização 2026-08-15

Separar medição física, especificação oficial, estimativa e pendência; usar coupons pequenos antes de impressão completa.

## Atualização 2026-09-16

Adaptador USB-C passivo não regula tensão: queda do barramento aparece diretamente na saída. Distribuir Radxa, hub e tela em ramos próprios após o switch evita usar a Radxa ou o hub como caminho principal de potência. Não congelar CAD antes de receber e medir o hardware real.

## Template

### LES-### — Título

- Contexto:
- O que aprendemos:
- Evidência:
- Como muda o trabalho futuro:
- Referências:

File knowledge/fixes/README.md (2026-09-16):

# Correções

Correções importadas e seus contextos estão em [../bugs/engineering_error_history.md](../bugs/engineering_error_history.md):

- `ERROR-0001`: saúde SSH via `ssh.service`, não `ssh.socket`.
- `ERROR-0002`: journal do SSH com privilégios adequados.
- `ERROR-0003`: `libxcb-cursor0` para a dependência Qt ausente.
- `ERROR-0004`: usar o virtualenv localizado no projeto.
- `ERROR-0005`: iniciar GUI por script que ativa `.venv`.
- `ERROR-0007`: executar Python como módulo.
- `ERROR-0008`: parar serviço systemd de usuário antes de testar a GUI.

Para novas correções, explicar por que funcionou, por que tentativas anteriores falharam, versões/ambiente, evidências, rollback e melhoria futura.

Os marcos positivos associados estão em [../successes/engineering_success_history.md](../successes/engineering_success_history.md).

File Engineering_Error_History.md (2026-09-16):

# Engineering Error History — SatoOne

**Versão:** 1.1  
**Status:** Registro canônico de falhas e depuração  
**Última atualização:** 2026-08-04

## Atualização de pendências mecânicas — 2026-08-15

### MECH-001 — Inconsistência no padrão de furos do teclado

- **Status:** Aberto / NEEDS_REVALIDATION
- **Evidência:** horizontal 53.59 mm, vertical 39.46 mm e diagonal anterior 68.91 mm não devem ser tratados como conjunto CAD validado.
- **Prevenção:** não liberar fixação definitiva do teclado até nova medição.

### MECH-002 — Desenho de fixação do display ainda pendente

- **Status:** Aberto
- **Evidência:** display identificado como Waveshare 5DP-CAPLCD-H e envelope medido; desenho oficial e coordenadas dos furos ainda não conferidos.
- **Prevenção:** não inventar coordenadas nem usar variantes B/G.

## Propósito

Preservar tudo que deu errado: erros, comportamentos inesperados, investigações, tentativas descartadas e pendências. Nunca apagar histórico; corrigir ou complementar entradas com uma nova seção datada. Consulte este arquivo antes de reproduzir uma investigação.

## Como registrar

Cada entrada deve conter: ID, data, categoria, status, impacto, ambiente, sintomas, comandos/ações, causa raiz ou hipótese, tentativas que falharam, solução/workaround, evidência, prevenção e links relacionados.

**Estados:** `Aberto`, `Em investigação`, `Resolvido`, `Monitorando`, `Não reproduzido`.

## Índice

| ID | Título | Categoria | Estado | Solução / próximo passo |
| --- | --- | --- | --- | --- |
| ERROR-0001 | SSH parecia inativo | Linux/systemd | Resolvido | Validar `ssh.service`, não `ssh.socket` |
| ERROR-0002 | Journal do SSH vazio | Linux | Resolvido | Usar privilégios adequados |
| ERROR-0003 | Plugin PySide6 ausente | Qt/Python | Resolvido | Instalar `libxcb-cursor0` |
| ERROR-0004 | Caminho do virtualenv incorreto | Python | Resolvido | Usar `.venv` do projeto |
| ERROR-0005 | Autostart sem janela | Linux/XFCE | Resolvido | Launcher ativa virtualenv |
| ERROR-0006 | Splash parecia sem animação | PySide6/UX | Resolvido | Renderização customizada planejada |
| ERROR-0007 | `ModuleNotFoundError: widgets` | Python | Resolvido | Executar como módulo |
| ERROR-0008 | Aplicação relançava em loop | systemd | Resolvido | Parar serviço durante debug |
| ERROR-0009 | Display atual desproporcional | Hardware/UX | Aberto | Avaliar display 4" 720×720 |
| ERROR-0010 | Splash com acabamento simples | UX | Aberto | Experimentar QPainter e efeitos |

## Registros detalhados

### ERROR-0001 — Serviço SSH parecia inativo

- **Data:** histórica não registrada; importado em 2026-08-04
- **Impacto:** falso diagnóstico de que o servidor SSH não estava em execução.
- **Ambiente:** Linux com systemd e SSH configurado com socket activation.
- **Sintoma:** `ssh.service` parecia `DEAD` após o boot ou ao comparar com o socket.
- **Investigação:** `systemctl status ssh`; `systemctl status ssh.socket`; `systemctl show ssh`; `journalctl -u ssh`; `systemctl cat ssh`.
- **Causa raiz:** `ssh.socket` ativa o serviço sob demanda; ao iniciar `ssh.service` manualmente, o socket pode ficar inativo. É comportamento esperado.
- **Solução:** usar `ssh.service` como indicador de saúde; não inferir falha pelo estado de `ssh.socket`.
- **Prevenção:** entender a unidade systemd e seu modo de ativação antes de diagnosticar falha.

### ERROR-0002 — Journal do SSH vazio

- **Data:** histórica não registrada; importado em 2026-08-04
- **Impacto:** ausência aparente de logs para depuração.
- **Comando:** `journalctl -u ssh -b`.
- **Causa raiz:** usuário sem permissão para acessar o journal completo.
- **Solução:** executar `sudo journalctl -u ssh -b`.
- **Prevenção:** registrar nível de privilégio e redigir segredos antes de salvar logs.

### ERROR-0003 — Plugin PySide6 ausente

- **Data:** histórica não registrada; importado em 2026-08-04
- **Impacto:** aplicação PySide6 não iniciava.
- **Comando:** `ldd libqxcb.so`.
- **Causa raiz:** `libxcb-cursor.so.0` ausente.
- **Solução:** instalar `libxcb-cursor0`.
- **Evidência:** PySide6 passou a executar corretamente, segundo o histórico importado.
- **Prevenção:** inspecionar dependências do plugin Qt com `ldd`.

### ERROR-0004 — Caminho do virtualenv incorreto

- **Data:** histórica não registrada; importado em 2026-08-04
- **Sintoma:** `find ~/.venv` não retornou o ambiente esperado.
- **Causa raiz:** ambiente localizado em `~/Projetos/SatoOne/.venv`.
- **Solução:** confirmar e usar o virtualenv do projeto.
- **Prevenção:** não supor localização de ambiente Python.

### ERROR-0005 — Autostart falhou

- **Data:** histórica não registrada; importado em 2026-08-04
- **Sintoma:** entrada `.desktop` era executada, mas nenhuma janela aparecia.
- **Causa raiz:** Python era iniciado diretamente sem ativar `.venv`.
- **Solução:** `.desktop` chama `start_satoone.sh`, que ativa o ambiente e abre o app.
- **Prevenção:** validar o launcher no ambiente equivalente ao login gráfico.

### ERROR-0006 — Splash parecia sem animação

- **Data:** histórica não registrada; importado em 2026-08-04
- **Sintoma:** barra parecia imóvel.
- **Investigação:** `print()` em `QTimer` confirmou os ticks.
- **Causa raiz:** timer e repaint funcionavam; PNG estático não produz animação percebida. Era uma lacuna de design, não de loop Qt.
- **Solução:** substituir por renderização customizada; Particle Engine, glow e QPainter seguem planejados.
- **Prevenção:** validar lógica, repaint e asset separadamente.

### ERROR-0007 — `ModuleNotFoundError: widgets`

- **Data:** histórica não registrada; importado em 2026-08-04
- **Causa raiz:** `python app/splash.py` não incluía a raiz do projeto em `sys.path`.
- **Solução:** usar `python -m app.splash` ou configurar explicitamente o caminho de projeto.
- **Prevenção:** preferir execução modular e imports absolutos de pacote.

### ERROR-0008 — Loop de relançamento

- **Data:** histórica não registrada; importado em 2026-08-04
- **Sintoma:** aplicação reabria após ser fechada.
- **Comando de investigação:** `systemctl --user status`.
- **Causa raiz:** serviço systemd de usuário configurado para reiniciar o processo.
- **Solução:** parar o serviço antes de testar fechamento manual da GUI.
- **Prevenção:** desabilitar restart automático na sessão de depuração manual.

### ERROR-0009 — Display atual grande demais

- **Data:** histórica não registrada; importado em 2026-08-04
- **Impacto:** Waveshare de 5" parece desproporcional ao teclado BlackBerry Q10 e reduz a aparência comercial.
- **Estado:** Aberto.
- **Direção atual:** avaliar HDMI IPS capacitivo de 4", 720×720.
- **Critérios de saída:** validar dimensões, encaixe, touch, brilho, consumo e compatibilidade Linux.

### ERROR-0010 — Splash simples demais

- **Data:** histórica não registrada; importado em 2026-08-04
- **Impacto:** aparência de protótipo.
- **Estado:** Aberto.
- **Lacunas:** glow, partículas, progresso customizado e fade.
- **Próximo experimento:** QPainter com metas de FPS/CPU no Radxa.

## Template

### ERROR-#### — Título

- **Data:**
- **Categoria / responsável:**
- **Status:**
- **Impacto:**
- **Ambiente e versões:**
- **Sintomas:**
- **Comandos e ações executados:**
- **Hipótese / causa raiz:**
- **Tentativas descartadas:**
- **Solução ou workaround:**
- **Evidência:**
- **Prevenção / lição:**
- **Links relacionados:**

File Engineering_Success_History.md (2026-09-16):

# Engineering Success History — SatoOne

**Versão:** 1.1  
**Status:** Registro canônico de conquistas e soluções reutilizáveis  
**Última atualização:** 2026-08-04

## Atualização de marcos — 2026-08-15

### SUCCESS-0017 — Bambu Lab A1 Mini recebida

- **Categoria:** Fabricação
- **Estado:** Concluído
- **Evidência:** impressora disponível fisicamente no laboratório.
- **Reuso:** projetar e validar o gabinete considerando o envelope da A1 Mini; usar PLA e coupons antes da peça completa.

### SUCCESS-0018 — Primeiro inventário dimensional físico

- **Categoria:** Mecânica
- **Estado:** Concluído para os envelopes registrados
- **Evidência:** medições reais com paquímetro do display, teclado, Radxa, UPS e hub.
- **Limites:** padrão de furos do teclado e coordenadas oficiais do display ainda pendentes.

## Propósito

Registrar tudo que deu certo, por que funcionou e como reutilizar com segurança. Um sucesso não elimina a necessidade de registrar versões, ambiente e limites conhecidos.

## Índice de sucessos

| ID | Marco | Estado | Reuso principal |
| --- | --- | --- | --- |
| SUCCESS-0001 | Arquitetura MVC/Python/PySide6 | Concluído | Base modular e testável |
| SUCCESS-0002 | Radxa Zero 3W | Concluído | Plataforma Linux embarcada |
| SUCCESS-0003 | Debian Bullseye + XFCE | Concluído | Ambiente base leve e estável |
| SUCCESS-0004 | Virtualenv no projeto | Concluído | Dependências isoladas |
| SUCCESS-0005 | Dependência Qt resolvida | Concluído | Diagnóstico com `ldd` |
| SUCCESS-0006 | Autostart funcional | Concluído | Launcher ativa `.venv` |
| SUCCESS-0007 | Splash inicial | Concluído | Base visual funcional |
| SUCCESS-0008 | QTimer validado | Concluído | Infraestrutura de animação |
| SUCCESS-0009 | Display Waveshare compatível | Concluído | HDMI + USB HID no Linux |
| SUCCESS-0010 | Direção de display futuro | Aprovado | 4" 720×720 em avaliação |
| SUCCESS-0011 | Teclado Q10 selecionado | Concluído | Referência mecânica |
| SUCCESS-0012 | Bambu Lab A1 Mini | Aprovado | Plataforma de prototipagem |
| SUCCESS-0013 | Estratégia mecânica | Concluído | Gabinete modular e reparável |
| SUCCESS-0014 | Estratégia documental | Concluído | Memória permanente |
| SUCCESS-0015 | Skills de engenharia | Concluído | Contexto e consistência |
| SUCCESS-0016 | Filosofia do produto | Concluído | Critério para decisões |

## Detalhes e reutilização

### SUCCESS-0001 a SUCCESS-0003 — Base de software e plataforma

MVC, Python, PySide6, Radxa Zero 3W (4 GB LPDDR4, 32 GB eMMC) e Debian Bullseye/XFCE formam a base aprovada. Funcionam juntos porque separam UI da lógica, usam uma pilha Linux leve e definem um alvo concreto. Reutilizar esta base até que uma ADR substitua algum elemento.

### SUCCESS-0004 a SUCCESS-0006 — Ambiente de execução confiável

O virtualenv em `~/Projetos/SatoOne/.venv`, o diagnóstico de dependência com `ldd` e o launcher `start_satoone.sh` resolvem isolamento Python, plugin Qt e autostart. Reutilizar o launcher para sessão gráfica e execução modular para desenvolvimento. Ver também `ERROR-0003`, `ERROR-0004`, `ERROR-0005` e `ERROR-0007`.

### SUCCESS-0007 e SUCCESS-0008 — Fundação da splash

A splash com logo, status, progresso e mensagens funciona; o `QTimer` completou 100 ticks. Isso comprova a base de temporização, mas não comprova efeitos visuais premium. Usar QPainter para a próxima iteração, conforme `ERROR-0006` e `ERROR-0010`.

### SUCCESS-0009 a SUCCESS-0013 — Direção física e mecânica

O Waveshare 1024×600 com HDMI e touch USB HID foi compatível com Linux. O teclado BlackBerry Q10 e a Bambu Lab A1 Mini definem restrições de gabinete. A direção de 4" 720×720 foi aprovada por proporção, mas permanece pendente de validação física. Projetar com manutenção, bateria, bordas arredondadas e parafusos ocultos.

### SUCCESS-0014 a SUCCESS-0016 — Processo de engenharia

`ENGINEERING_BIBLE.md`, a knowledge base e as skills SatoOne Development/Connect transformam decisões e descobertas em memória reutilizável. A filosofia de produto estabelece qualidade comercial, modularidade, Linux embarcado, UI premium, reparabilidade e fabricação futura como critérios de decisão.

## Template

### SUCCESS-#### — Título

- **Data:**
- **Categoria / responsável:**
- **Status:** Concluído / Aprovado / Monitorando
- **Objetivo:**
- **Implementação / decisão:**
- **Por que funcionou:**
- **Evidência e ambiente:**
- **Benefício:**
- **Limites conhecidos:**
- **Como reutilizar:**
- **Links relacionados:**

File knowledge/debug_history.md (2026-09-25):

# Histórico cronológico de depuração

| Data | Problema | Comandos / ações | Resultado | Conclusão |
| --- | --- | --- | --- | --- |
| 2026-08-04 | Histórico inicial importado | Criação da base de conhecimento | Itens anteriores registrados como não validados | Não inferir causa ou solução sem logs do dispositivo |
| 2026-08-04 | Importação de Error History v1.0 | Organização de 10 registros do anexo | 8 resolvidos; 2 abertos; comandos preservados | Consultar `knowledge/bugs/engineering_error_history.md` antes de depurar SSH, Qt, virtualenv, autostart ou splash |

## Auditorias recentes

### 2026-09-25 — Health check e baseline elétrico

- Raiz em eMMC, memória e rede disponíveis; aplicativo em falha recorrente de inicialização e atenção térmica.
- Coleta administrativa concluída; detalhes operacionais restritos ao relatório interno. Nenhuma correção aplicada.
- [Resumo público](benchmarks/2026-09-25-health-check.md) e [validação física relatada da alimentação](hardware/2026-09-25-power-baseline.md).

### 2026-09-17 — Health check operacional

- Coleta de recursos, armazenamento, sensores e periféricos, complementada por verificações direcionadas somente de leitura.
- Raiz em microSD confirmada; telemetria útil de bateria ausente; ambiente de aplicação diverge do caminho documentado.
- Pendências operacionais e limitações de acesso registradas no relatório interno excluído do Git; não interpretar ausência de logs administrativos como ausência de erros.
- Medições e método: [registro do health check](benchmarks/2026-09-17-health-check.md). Nenhuma correção ou reinicialização aplicada.

## Template de nova entrada

### YYYY-MM-DD — Título

- Problema:
- Ambiente:
- Comandos executados:
- Resultado:
- Conclusão / próximo passo:

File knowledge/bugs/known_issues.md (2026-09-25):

# Problemas conhecidos

O histórico completo — incluindo itens resolvidos, comandos e lições — está em [engineering_error_history.md](engineering_error_history.md). Esta lista contém apenas questões ainda abertas.

| ID | Problema | Status | Próximo passo |
| --- | --- | --- | --- |
| ERROR-0009 | Display Waveshare de 5" parece desproporcional ao teclado Q10 | Aberto | Avaliar e testar HDMI IPS de 4", 720×720 |
| ERROR-0010 | Splash ainda não possui acabamento visual premium | Aberto | Experimentar QPainter, glow, partículas e fade com metas de desempenho |
| MECH-001 | Padrão de furos do teclado inconsistente | Aberto / NEEDS_REVALIDATION | Medir novamente antes do CAD definitivo |
| MECH-002 | Coordenadas oficiais dos furos do display H não validadas | Aberto | Obter desenho mecânico H e confrontar com medição física |
| ELEC-001 | Power dedicado da tela + VBUS do USB Touch podem gerar backfeed | PENDING VALIDATION | Confirmar documentação e medir antes de manter as duas fontes |
| ELEC-002 | Limiares da proteção da LiPo não ensaiados | Validação parcial — 2026-09-25 | Pack recebido, proteção observada e operação com UPS antigo relatada; caracterização da proteção pendente |
| ELEC-003 | IP5310 não confiável na integração por fios/pads testada | EXPERIMENTAL / FUTURE — fora da montagem atual | Preservar o UPS antigo; reavaliar apenas em revisão futura |
| ELEC-004 | Posição e limite real do INA219 R100 indefinidos | PENDING DESIGN DECISION | Comparar medição antes/depois do boost e validar dissipação/queda |
| ELEC-005 | Autonomia definitiva e shutdown por bateria baixa ausentes | Aberto | Concluir ensaio, validar telemetria e implementar desligamento limpo |
| SW-001 | Aplicativo falha ao inicializar no health check de 25/09 | Aberto | Corrigir inicialização e repetir validação funcional; detalhes no relatório interno |

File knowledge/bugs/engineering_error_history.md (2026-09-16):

# Histórico de erros de engenharia — SatoOne

## ISSUE-MECH-006 — No external access to Radxa microSD

- **Revisão:** V1.2
- **Sintoma:** com a Radxa montada na Back, não há abertura validada para inserir/remover o microSD.
- **Causa:** V0/V1 foram criadas antes da validação de acesso a conectores laterais.
- **Correção proposta:** recorte lateral paramétrico na V1.2.
- **Status:** `OPEN_IN_V1_2_UNTIL_PHYSICAL_VALIDATION`.
- **Lição:** validar serviceability, acesso de cabos, mídia removível e clearance de conectores, não apenas o encaixe da PCB.

## ISSUE-MECH-006 — Lack of external access to Radxa microSD card

- **Sintoma:** após montar a Radxa, o cartão microSD não tinha acesso externo.
- **Impacto:** era necessário desmontar ou soltar a placa para trocar o cartão.
- **Correção:** recorte lateral paramétrico na revisão V1.2.
- **Status:** `IMPLEMENTED_IN_NEXT_REVISION`; posição ainda `NEEDS_PHYSICAL_VALIDATION`.
- **Lição:** validar acesso de manutenção com a placa montada, não apenas o envelope da PCB.

## ERROR/ISSUE-VENT-001 — Back ventilation slots did not cut through the internal floor

- **Data:** 2026-08-15
- **Sintoma:** ranhuras visíveis externamente, mas sem abertura até a cavidade interna.
- **Causa:** profundidade/posicionamento booleano insuficiente em relação ao piso.
- **Impacto:** ventilação apenas visual, não funcional.
- **Correção:** corte passante com `slot_cut_depth = wall + 1.0 mm` e centro em `wall / 2`.
- **Status:** `RESOLVED_IN_V1_1`; confirmar no slicer e na impressão física.
- **Lição:** validar booleanos passantes no preview por camada.

## Pendências/correções V1 — 2026-08-15

- **MECH-003 — Hub V0:** furação incorreta; V1 usa 51.03 × 14.92 mm, piloto Ø2.20 mm.
- **MECH-004 — Radxa V0:** furos apertados; V1 usa piloto Ø2.30 mm.
- **MECH-005 — UPS V0:** capacitores tocaram o fundo; V1 usa postes de 12.00 mm.

> Este arquivo permanece como fonte detalhada da knowledge base. O registro canônico para consulta geral é [Engineering_Error_History.md](../../Engineering_Error_History.md).

**Versão:** 1.0 importada em 2026-08-04  
**Propósito:** preservar cada erro, experimento falho, comportamento inesperado e sessão de depuração. Não apagar registros; adicionar correções e evidências posteriores.

## ERROR-0001 — Serviço SSH parecia inativo

- **Categoria:** Linux, systemd, SSH
- **Status:** Resolvido
- **Descrição:** após a inicialização, o serviço SSH aparentava estar `DEAD`.
- **Impacto:** a equipe acreditou que o servidor SSH não estava em execução.
- **Investigação:** `systemctl status ssh`, `systemctl status ssh.socket`, `systemctl show ssh`, `journalctl -u ssh`, `systemctl cat ssh`.
- **Causa raiz:** `ssh.socket` usa socket activation. Ao iniciar `ssh.service` manualmente, o socket pode ficar inativo; esse comportamento é esperado.
- **Solução:** validar a saúde por `ssh.service`, não pelo estado de `ssh.socket`.
- **Lição:** compreender socket activation do systemd antes de concluir que um serviço falhou.

## ERROR-0002 — Journal do SSH vazio

- **Categoria:** Linux
- **Status:** Resolvido
- **Descrição:** `journalctl -u ssh -b` não retornou entradas.
- **Impacto:** não havia informação de depuração disponível ao usuário comum.
- **Causa raiz:** permissões insuficientes para acessar o journal completo.
- **Solução:** executar `sudo journalctl -u ssh -b`.
- **Lição:** coletar logs de sistema com privilégios adequados; redigir segredos antes de anexá-los à documentação.

## ERROR-0003 — Plugin PySide6 ausente

- **Categoria:** Python, Qt
- **Status:** Resolvido
- **Descrição:** a aplicação PySide6 não iniciava.
- **Investigação:** `ldd libqxcb.so`.
- **Causa raiz:** biblioteca `libxcb-cursor.so.0` ausente.
- **Solução:** instalar o pacote `libxcb-cursor0`.
- **Lição:** verificar dependências Qt com `ldd` quando o plugin de plataforma não carregar.

## ERROR-0004 — Caminho do ambiente virtual Python

- **Categoria:** Python
- **Status:** Resolvido
- **Descrição:** a busca pelo ambiente virtual foi feita no local errado com `find ~/.venv`.
- **Causa raiz:** o ambiente virtual estava dentro do projeto: `~/Projetos/SatoOne/.venv`.
- **Solução:** confirmar e usar o ambiente virtual do projeto.
- **Lição:** não assumir a localização do virtualenv; verificá-la antes de diagnosticar dependências.

## ERROR-0005 — Autostart falhou

- **Categoria:** Linux, XFCE
- **Status:** Resolvido
- **Descrição:** a entrada `.desktop` iniciava, mas nenhuma janela aparecia.
- **Causa raiz:** a entrada executava Python diretamente, sem ativar o virtualenv.
- **Solução:** criar `start_satoone.sh`, ativar `.venv` e iniciar a aplicação pelo script.
- **Lição:** não executar Python diretamente em uma entrada desktop quando o projeto depende de virtualenv.

## ERROR-0006 — Animação da splash não se movia

- **Categoria:** PySide6, UX
- **Status:** Resolvido (diagnóstico); evolução planejada
- **Descrição:** splash carregava, mas a barra de progresso parecia estática.
- **Investigação:** adicionado `print()` ao `QTimer`; os ticks ocorreram.
- **Causa raiz:** a lógica de animação e repaint do Qt funcionavam; a imagem PNG era estática. O problema era a expectativa visual do design.
- **Solução:** substituir a falsa animação por renderização customizada.
- **Próximos passos:** Particle Engine, glow e QPainter.
- **Lição:** separar falha de lógica de limitação do asset/expectativa de design antes de alterar o loop de renderização.

## ERROR-0007 — `ModuleNotFoundError: widgets`

- **Categoria:** Python
- **Status:** Resolvido
- **Descrição:** o módulo `widgets` não era importado.
- **Causa raiz:** aplicação iniciada com `python app/splash.py`; a raiz do projeto não estava em `sys.path`.
- **Solução:** iniciar com `python -m app.splash` ou inserir explicitamente a raiz do projeto no caminho de importação.
- **Lição:** preferir execução como módulo e evitar imports relativos frágeis em scripts executáveis.

## ERROR-0008 — Loop de relançamento do SatoOne

- **Categoria:** systemd, autostart
- **Status:** Resolvido
- **Descrição:** a aplicação reabria depois de ser fechada.
- **Investigação:** `systemctl --user status`.
- **Causa raiz:** serviço systemd de usuário reiniciava a aplicação automaticamente.
- **Solução:** interromper o serviço antes de testar o fechamento da GUI.
- **Lição:** desativar restart automático durante depuração manual de interface.

## ERROR-0009 — Display atual grande demais

- **Categoria:** Hardware, UX
- **Status:** Aberto
- **Descrição:** display Waveshare de 5" parece visualmente grande em relação ao teclado BlackBerry Q10.
- **Impacto:** o protótipo perde proporção de handheld comercial.
- **Decisão atual:** avaliar display HDMI IPS de 4", 720×720.
- **Próximo passo:** obter hardware e validar encaixe, touch, brilho, consumo e compatibilidade Linux.

## ERROR-0010 — Design da splash simples demais

- **Categoria:** UX, PySide6
- **Status:** Aberto
- **Descrição:** splash ainda parece protótipo.
- **Lacunas:** glow, partículas, barra de progresso customizada e fade.
- **Decisão atual:** implementação futura com QPainter.
- **Próximo passo:** criar experimento com meta de FPS e orçamento de CPU no Radxa.

## Lições gerais

- Nunca assumir comportamento do Linux.
- Documentar a depuração e os comandos executados.
- Não repetir problemas já resolvidos; consultar este histórico e `knowledge/fixes/` primeiro.
- Todo erro de engenharia é conhecimento permanente do projeto.

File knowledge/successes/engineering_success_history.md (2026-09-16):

# Histórico de acertos de engenharia — SatoOne

## SUCCESS-0022 — Requisito de acesso microSD incorporado — 2026-08-15

- O requisito de troca do microSD sem desmontar a case foi incorporado à V1.2.
- O recorte é paramétrico, arredondado e passante.
- A posição permanece provisória até validação física, preservando a distinção entre CAD proposto e geometria confirmada.

## SUCCESS-0022 — Requisito de manutenção do microSD incorporado — 2026-08-15

- Criada revisão V1.2 sem sobrescrever versões anteriores.
- Recorte lateral paramétrico adicionado no lado da Radxa.
- A posição foi explicitamente mantida provisória até medição física do slot.

## SUCCESS-0021 — V1.1 corrige ventilação funcional — 2026-08-15

- V0 foi impressa com sucesso na A1 Mini.
- Radxa, UPS e hub foram validados no layout físico.
- V1.1 transforma as ranhuras da Back em cortes realmente passantes sem alterar os demais componentes funcionais.

## SUCCESS-0019 — Back V0 impresso e validado — 2026-08-15

- Back V0 impresso na Bambu Lab A1 Mini.
- Radxa coube na região planejada; footprint XY da UPS foi compatível; altura do hub foi adequada.
- O fluxo CAD → STL → Bambu Studio → A1 Mini foi confirmado.

## SUCCESS-0020 — Correções V1 derivadas de teste físico — 2026-08-15

- Hub corrigido para 51.03 × 14.92 mm e piloto Ø2.20 mm.
- Radxa corrigida para piloto Ø2.30 mm.
- UPS elevada para postes de 12.00 mm para clearance dos capacitores.

> Este arquivo permanece como fonte detalhada da knowledge base. O registro canônico para consulta geral é [Engineering_Success_History.md](../../Engineering_Success_History.md).

**Versão:** 1.0 importada em 2026-08-04  
**Propósito:** registrar conquistas, soluções validadas e marcos reutilizáveis. Cada sucesso deve explicar por que funcionou e apontar limites ou próxima validação.

## SUCCESS-0001 — Arquitetura inicial definida

- **Categoria:** Arquitetura de software
- **Status:** Concluído
- **Decisão:** MVC, Python, PySide6 e design modular.
- **Resultado:** base escalável, com responsabilidades separadas e melhor testabilidade.
- **Reutilização:** suportar plugins e componentes modulares sem concentrar lógica em widgets.

## SUCCESS-0002 — Radxa Zero 3W selecionado

- **Categoria:** Hardware
- **Status:** Concluído
- **Plataforma:** Radxa Zero 3W, 4 GB LPDDR4 e 32 GB eMMC.
- **Motivo:** suporte Linux, tamanho compacto, baixo consumo, Wi-Fi e Bluetooth integrados.
- **Resultado:** plataforma de hardware definida para desenvolvimento.

## SUCCESS-0003 — Sistema operacional padronizado

- **Categoria:** Linux
- **Status:** Concluído
- **Decisão:** Debian Bullseye com XFCE.
- **Motivo:** base estável, leve e compatível com Qt.
- **Reutilização:** manter esta combinação como referência de ambiente até uma decisão de migração documentada.

## SUCCESS-0004 — Ambiente Python padronizado

- **Categoria:** Python
- **Status:** Concluído
- **Decisão:** virtualenv dedicado no projeto, em `~/Projetos/SatoOne/.venv`.
- **Resultado:** isolamento de dependências, deploy repetível e backup simples.
- **Referência:** `ERROR-0004`.

## SUCCESS-0005 — Dependência Qt resolvida

- **Categoria:** Qt
- **Status:** Concluído
- **Resultado:** PySide6 iniciou após a instalação de `libxcb-cursor0` para suprir `libxcb-cursor.so.0`.
- **Por que funcionou:** o plugin de plataforma dependia da biblioteca ausente; `ldd libqxcb.so` identificou a dependência.
- **Reutilização:** diagnosticar falhas de plugin Qt com `ldd`.
- **Referência:** `ERROR-0003`.

## SUCCESS-0006 — Autostart funcional

- **Categoria:** Linux
- **Status:** Concluído
- **Implementação:** entrada `.desktop` chama `start_satoone.sh`, que ativa o virtualenv e inicia o app.
- **Resultado:** inicialização automática confiável após login.
- **Referência:** `ERROR-0005`.

## SUCCESS-0007 — Primeira splash funcional

- **Categoria:** UI
- **Status:** Concluído
- **Entregue:** logo, status, barra de progresso e mensagens de carregamento.
- **Resultado:** protótipo de splash funcional.
- **Próxima evolução:** Particle Engine, glow e fade.

## SUCCESS-0008 — QTimer validado

- **Categoria:** Qt
- **Status:** Concluído
- **Evidência registrada:** 100 ticks de timer executados.
- **Conclusão:** infraestrutura de temporização/animação opera corretamente; uma PNG estática não representa falha de repaint.
- **Referência:** `ERROR-0006`.

## SUCCESS-0009 — Compatibilidade do display confirmada

- **Categoria:** Hardware
- **Status:** Concluído
- **Display:** Waveshare 1024×600, HDMI, touch capacitivo USB HID.
- **Resultado:** compatibilidade Linux confirmada.
- **Limite:** proporções físicas seguem em avaliação em `ERROR-0009`.

## SUCCESS-0010 — Direção do display futuro aprovada

- **Categoria:** Hardware
- **Status:** Aprovado
- **Direção:** HDMI capacitivo de 4", 720×720.
- **Motivo:** proporções melhores e aparência comercial.
- **Limite:** aprovação de direção não substitui testes de compatibilidade, consumo e encaixe.

## SUCCESS-0011 — Teclado BlackBerry Q10 selecionado

- **Categoria:** Hardware
- **Status:** Concluído
- **Motivo:** digitação, tamanho compacto e aparência profissional.
- **Resultado:** planejamento mecânico iniciado.

## SUCCESS-0012 — Plataforma de impressão 3D selecionada

- **Categoria:** Mecânica
- **Status:** Aprovado
- **Decisão:** Bambu Lab A1 Mini.
- **Motivo:** precisão, confiabilidade e software.
- **Reutilização:** projetar o gabinete considerando o envelope e os perfis da impressora.

## SUCCESS-0013 — Estratégia mecânica definida

- **Categoria:** Mecânica
- **Status:** Concluído
- **Decisão:** gabinete desenhado do zero, comercial, modular e reparável; cantos arredondados, parafusos ocultos, compartimento de bateria e manutenção acessível.

## SUCCESS-0014 — Estratégia de documentação criada

- **Categoria:** Engenharia
- **Status:** Concluído
- **Resultado:** base de conhecimento, histórico, inventário, hardware, software, roadmap, lições e debug são mantidos como memória permanente.
- **Reutilização:** agentes futuros devem consultar `ENGINEERING_BIBLE.md` e `knowledge/` antes de agir.

## SUCCESS-0015 — Skills de engenharia criadas

- **Categoria:** Desenvolvimento
- **Status:** Concluído
- **Skills:** SatoOne Development e SatoOne Connect.
- **Resultado:** contexto persistente, maior consistência de engenharia e orientação de qualidade.

## SUCCESS-0016 — Filosofia do projeto definida

- **Categoria:** Engenharia
- **Status:** Concluído
- **Princípios:** qualidade comercial, modularidade, Linux embarcado, UI premium, reparabilidade, manutenção e fabricação futura.
- **Referências:** `Vision.md`, `PRD.md` e `ENGINEERING_BIBLE.md`.

## Princípio de engenharia

Toda implementação bem-sucedida deve ser documentada com o motivo do sucesso. Reutilize soluções comprovadas antes de inventar abordagens novas; conhecimento do projeto é um ativo permanente.

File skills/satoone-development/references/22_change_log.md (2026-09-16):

# Change log

Consultar e atualizar `CHANGELOG.md` para mudanças significativas. Nunca alterar uma entrada histórica sem registrar correção posterior.

Registrar a data real da decisão/desenvolvimento separadamente da data em que a documentação ou página pública foi atualizada. Para a direção V1 atual, usar 2026-09-15 como data técnica e 2026-09-16 como consolidação pública.

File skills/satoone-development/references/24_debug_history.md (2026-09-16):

# Histórico de depuração

Consultar e atualizar `knowledge/debug_history.md`. Registrar data, problema, ambiente, comandos, resultados e conclusão; remover segredos antes de persistir logs.

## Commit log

2026-09-16 Initial SatoOne project release
    [SatoOne_Case_V0_Back.stl, SatoOne_Case_V0_Clamps.stl, SatoOne_Case_V0_Front.stl]
2026-09-16 Publish V1 engineering plan and prototype gallery
2026-09-16 Add V0 prototype demonstration video
2026-09-16 docs(satoone): update power architecture and purchased hardware
2026-09-25 Document validated power baseline and September 25 health check
